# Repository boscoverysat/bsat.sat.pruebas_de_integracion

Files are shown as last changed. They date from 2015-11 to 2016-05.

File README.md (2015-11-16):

# Prebas de Integración

## Resumen

Este repositrio contiene tanto el código como la circuitería necesaria para poder realizar la implementación del satélite.

## Elementos

### [Processing](processing/)

Contiene el código empleado para poder llevar a cabo la representación gráfica del comportamiento del satélite.

### [PCB](pcb/)

Contiene los diseños y esquemas eléctricos correspondientes a las placas de circuito impreso empleadas para el satélite.

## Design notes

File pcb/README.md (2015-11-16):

# PCB

## Resumen

Esta sección del repositorio contiene los diseños y circuitos electrónicos correspondientes a las placas de circuito impreso del satélite.

## Elementos

### [Receptor RF 430MHz](receptor_rf_430mhz/)

Diseño de receptor para capturar localmente mediante Arduino, los datos enviados por el satélite.

### [SAT Battery Shield](sat_battery_shield/)

Diseño de la placa encargada de contener el sistema de alimentación del satélite.

### [SAT Control Shield](sat_control_shield/)

Diseño de la placa donde se ubicará el cerebro del del satélite así como los sitemas de control inercial y orientación.

### [SAT Transmission Shield](sat_transmission_shield/)

Diseño de la placa encargada de contener el sistema de transmisión por radiofrecuencia del satélite.

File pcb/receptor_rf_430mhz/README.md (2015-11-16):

# Receptor RF 430MHz

## Resumen

Esta sección del repositorio contiene el circuito electrónico y el diseño de placa de circuito impreso del receptor de radiofracuencia, para capturar localmente y mediante Arduino, los datos enviados desde el satélite.

El diseño electrónico se ha llevado a cabo mediante el software **Eagle PCB**.

#### Diseño PCB

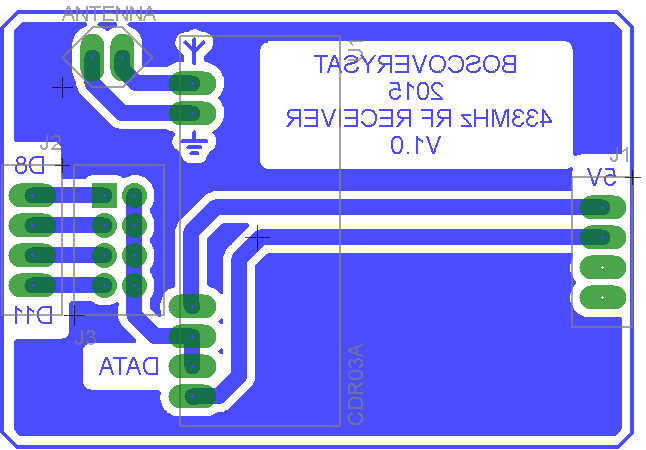
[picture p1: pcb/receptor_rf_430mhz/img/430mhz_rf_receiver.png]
Diseño de PCB


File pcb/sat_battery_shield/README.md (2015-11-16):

# SAT Battery Shield

## Resumen

Esta sección del repositorio contiene el circuito electrónico y el diseño de placa de circuito impreso para el sistema de alimentación del satélite.

El diseño electrónico se ha llevado a cabo mediante el software **Eagle PCB**.

#### Diseño PCB

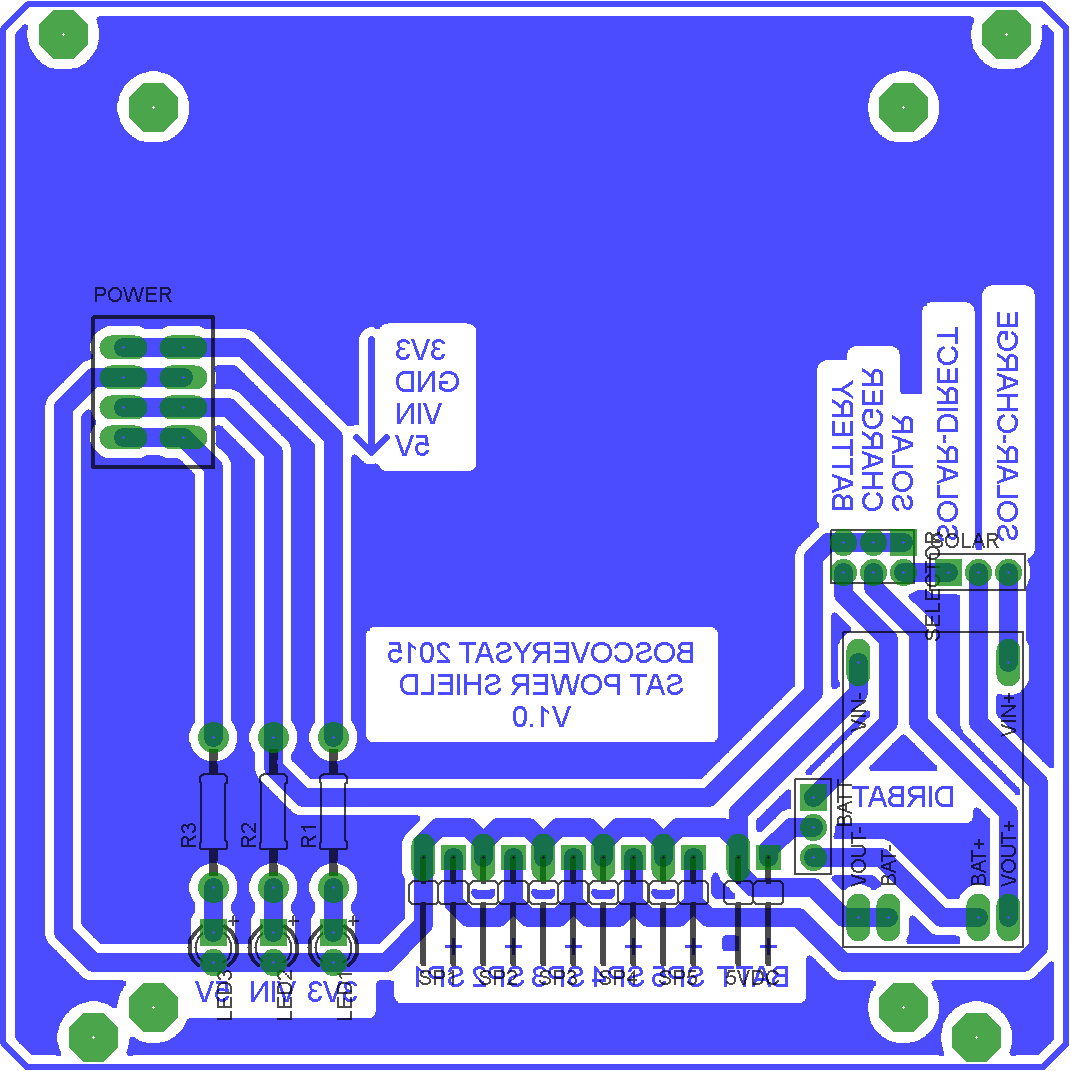
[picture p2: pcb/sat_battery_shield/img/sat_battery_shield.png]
Diseño de PCB


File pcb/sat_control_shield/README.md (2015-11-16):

# SAT Control Shield

## Resumen

Esta sección del repositorio contiene el circuito electrónico y el diseño de placa de circuito impreso para el sistema de control del satélite.

El diseño electrónico se ha llevado a cabo mediante el software **Eagle PCB**.

#### Diseño PCB

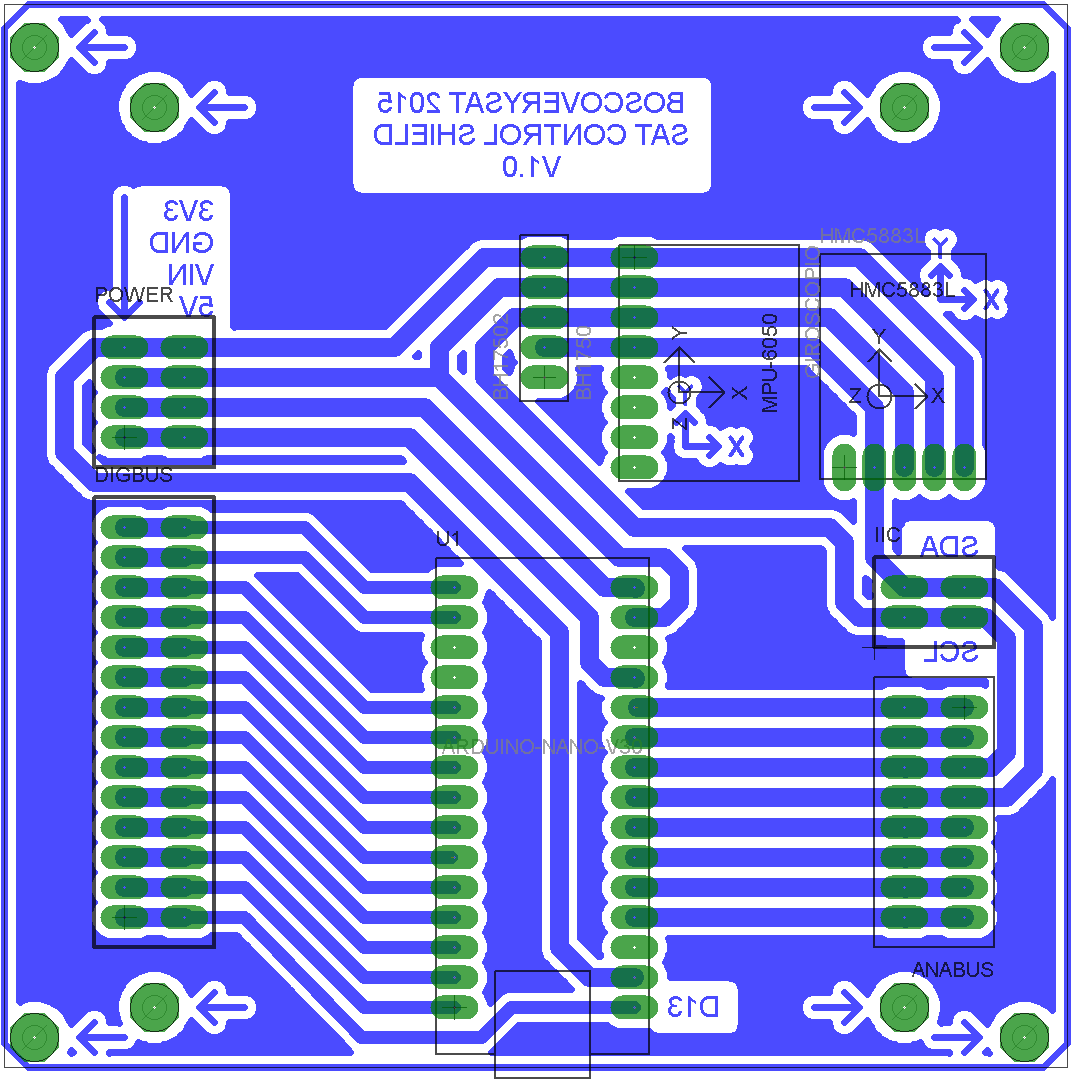
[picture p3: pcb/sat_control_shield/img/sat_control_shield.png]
Diseño de PCB


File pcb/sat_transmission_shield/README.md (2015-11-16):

# SAT Trasmission Shield

## Resumen

Esta sección del repositorio contiene el circuito electrónico y el diseño de placa de circuito impreso para el sistema de transmisión por radiofrecuencia del satélite.

El diseño electrónico se ha llevado a cabo mediante el software **Eagle PCB**.

#### Diseño PCB

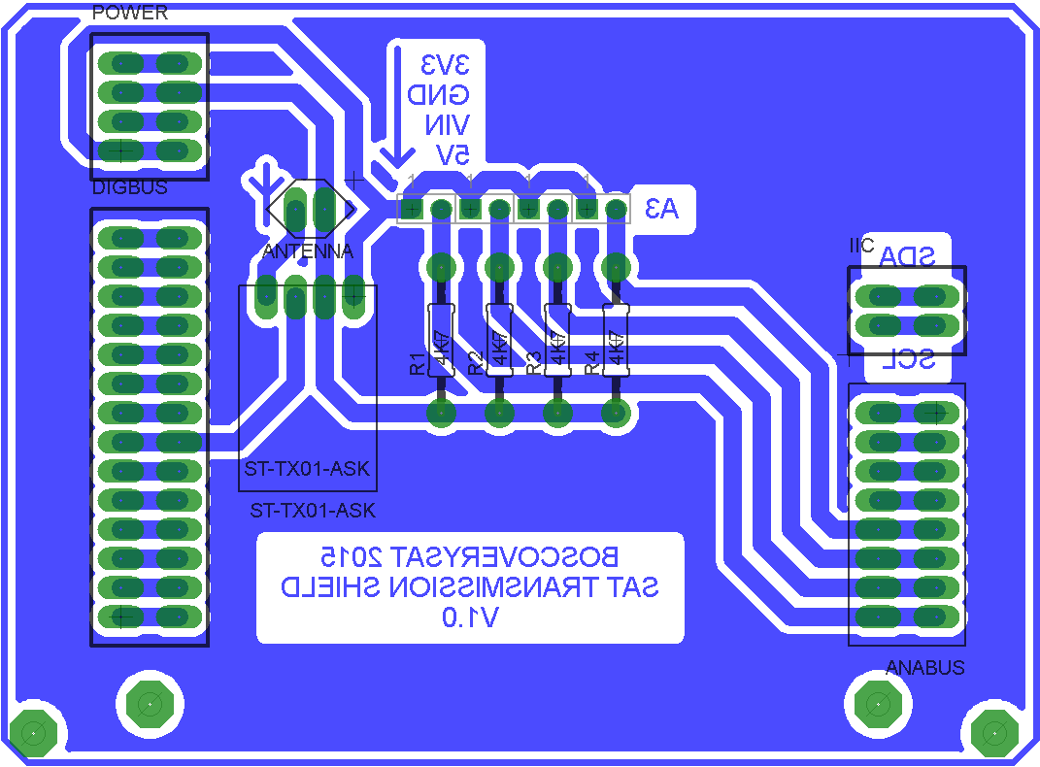
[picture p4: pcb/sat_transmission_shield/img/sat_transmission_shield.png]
Diseño de PCB


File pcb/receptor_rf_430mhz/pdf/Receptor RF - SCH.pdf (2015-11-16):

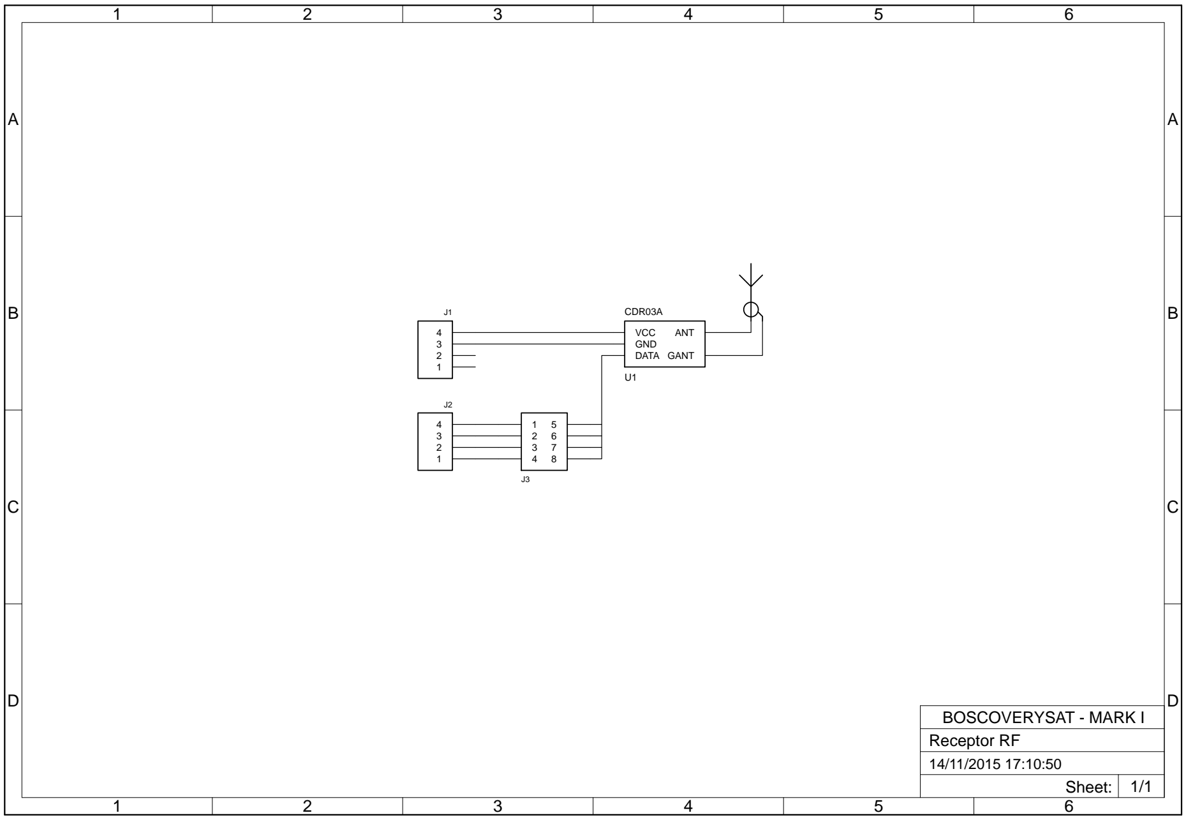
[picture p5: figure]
CDR03A; VCC; DATA; GND; ANT; GANT; Receptor RF; Sheet: 1/1; BOSCOVERYSAT - MARK I

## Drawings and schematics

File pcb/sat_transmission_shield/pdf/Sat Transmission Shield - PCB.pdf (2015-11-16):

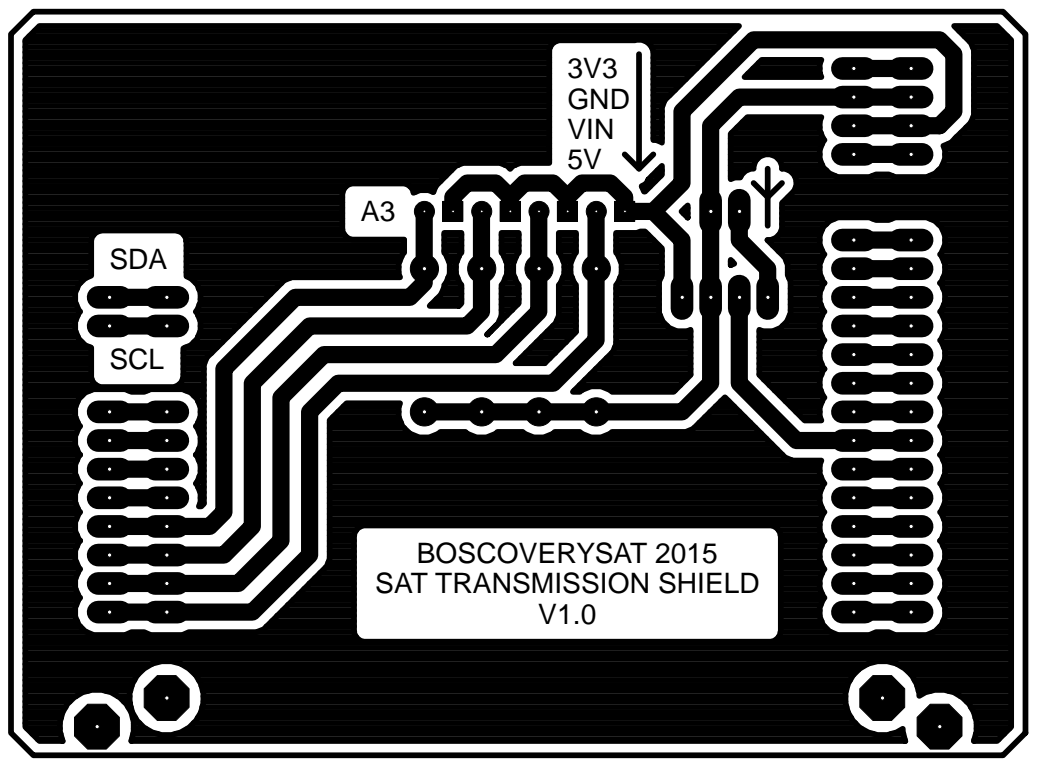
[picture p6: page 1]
3V3 GND VIN 5V; SCL; SDA

BOSCOVERYSAT 2015
SAT TRANSMISSION SHIELD

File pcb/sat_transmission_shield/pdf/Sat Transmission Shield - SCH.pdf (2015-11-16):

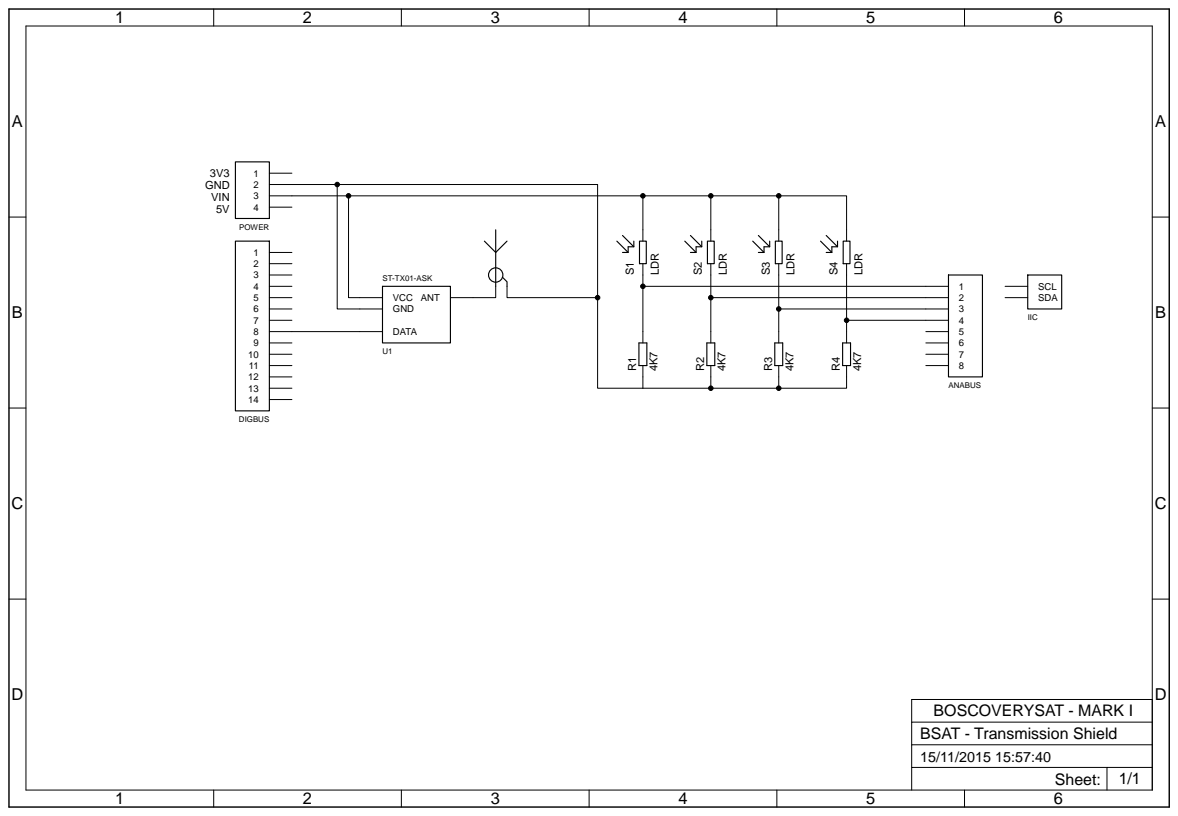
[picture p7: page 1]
3V3 GND VIN 5V; ST-TX01-ASK; LDR 4K7; DIGBUS; POWER; SCL SDA; IIC; VCC GND; DATA; ANT; ANABUS; Sheet: 1/1

BOSCOVERYSAT - MARK I
BSAT - Transmission Shield

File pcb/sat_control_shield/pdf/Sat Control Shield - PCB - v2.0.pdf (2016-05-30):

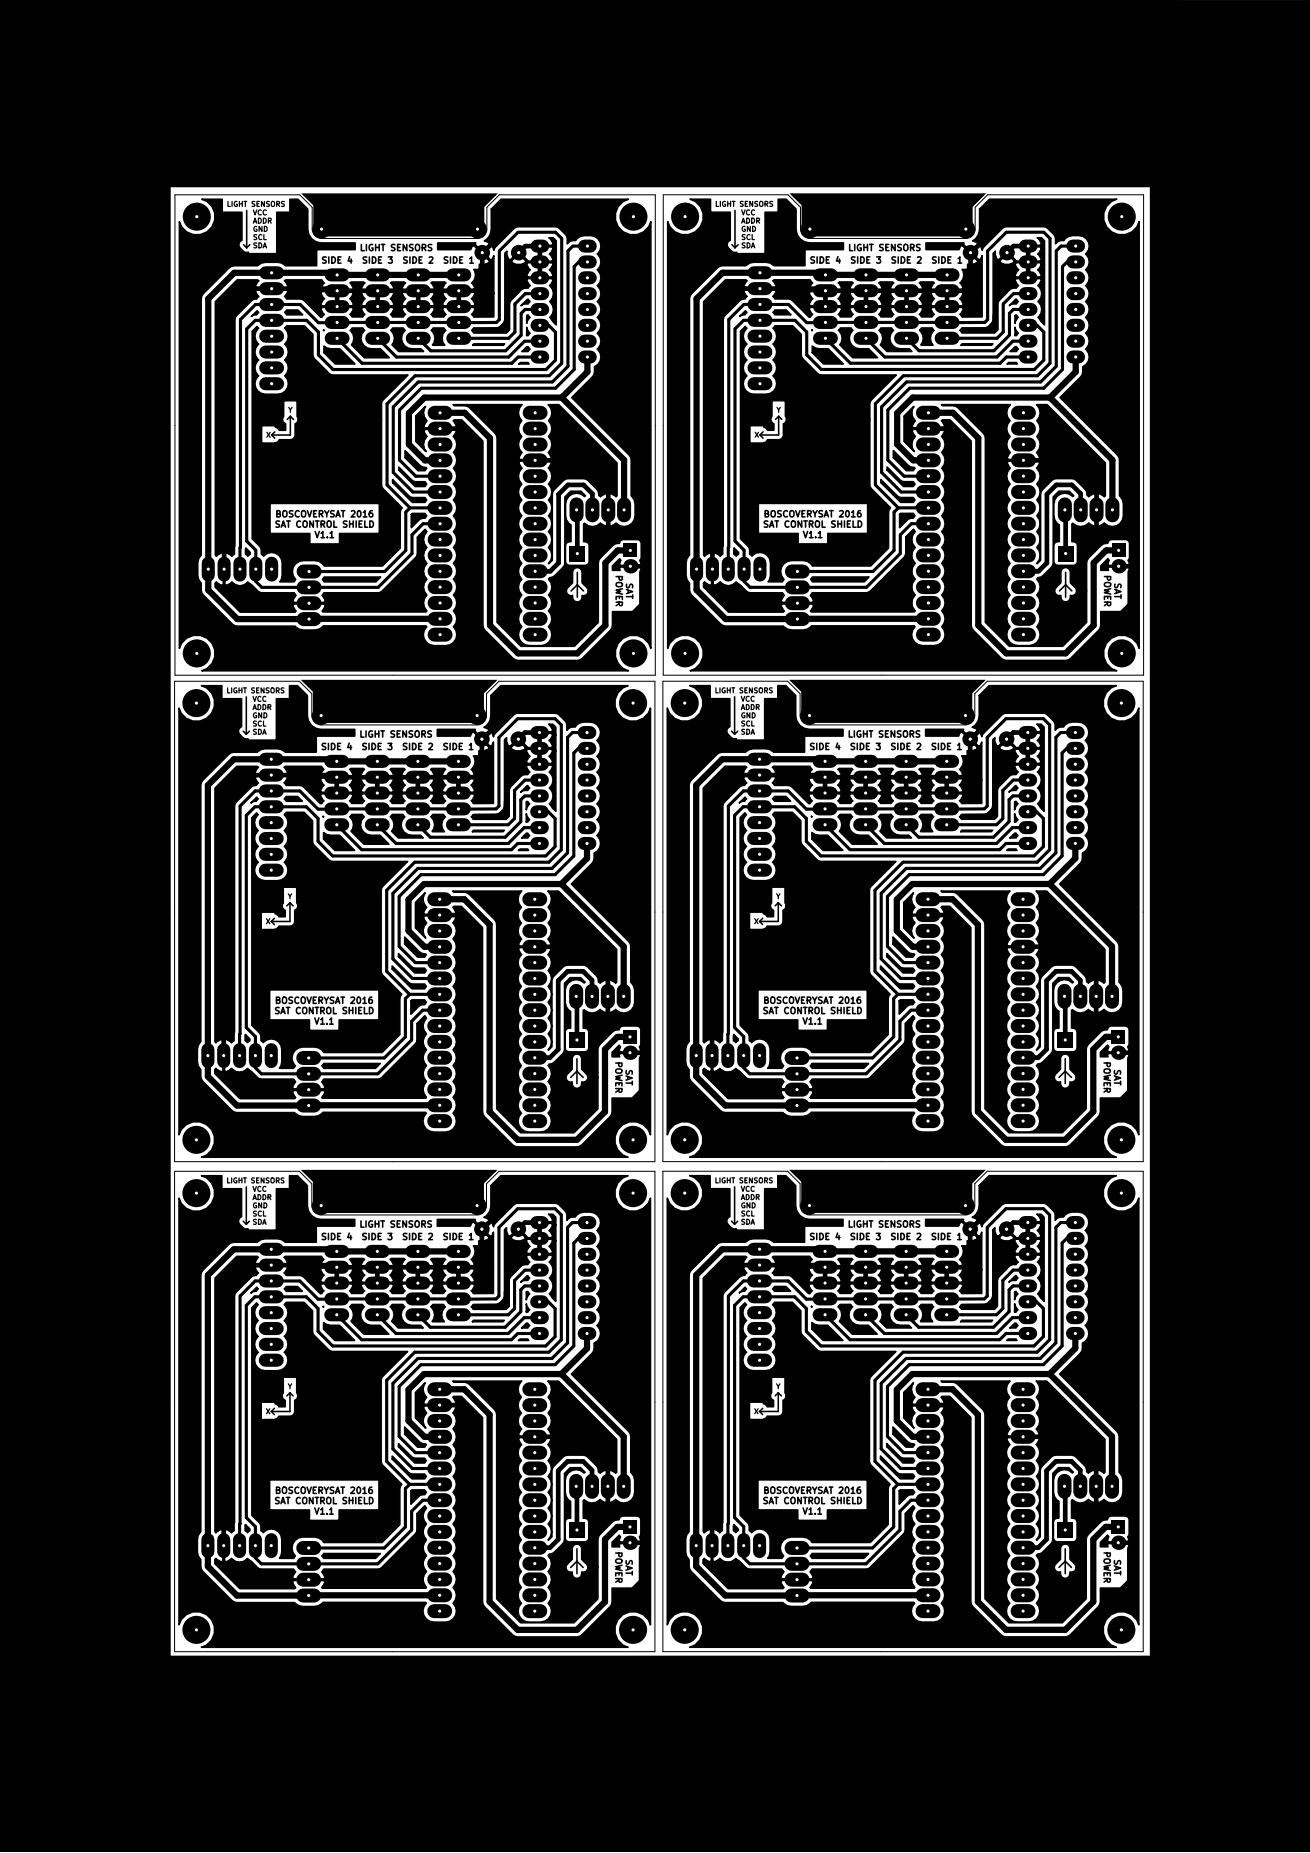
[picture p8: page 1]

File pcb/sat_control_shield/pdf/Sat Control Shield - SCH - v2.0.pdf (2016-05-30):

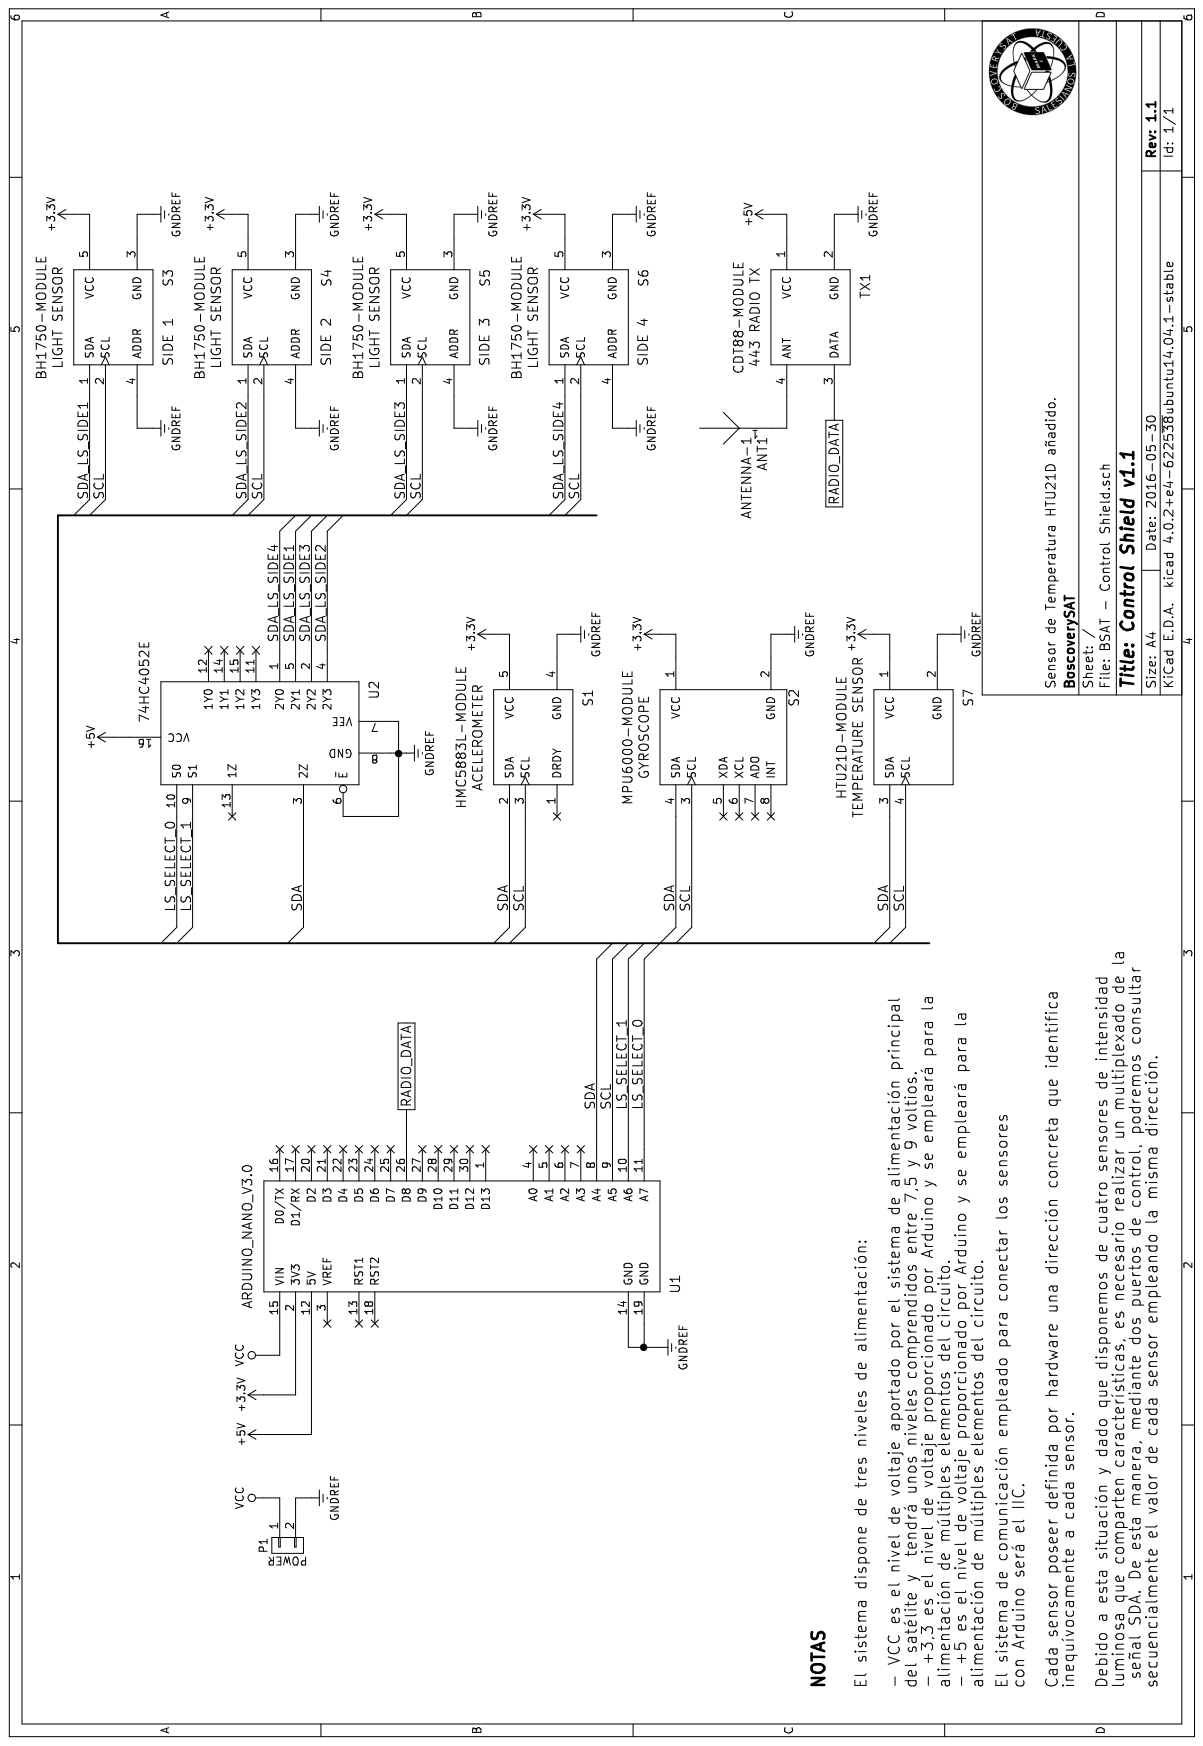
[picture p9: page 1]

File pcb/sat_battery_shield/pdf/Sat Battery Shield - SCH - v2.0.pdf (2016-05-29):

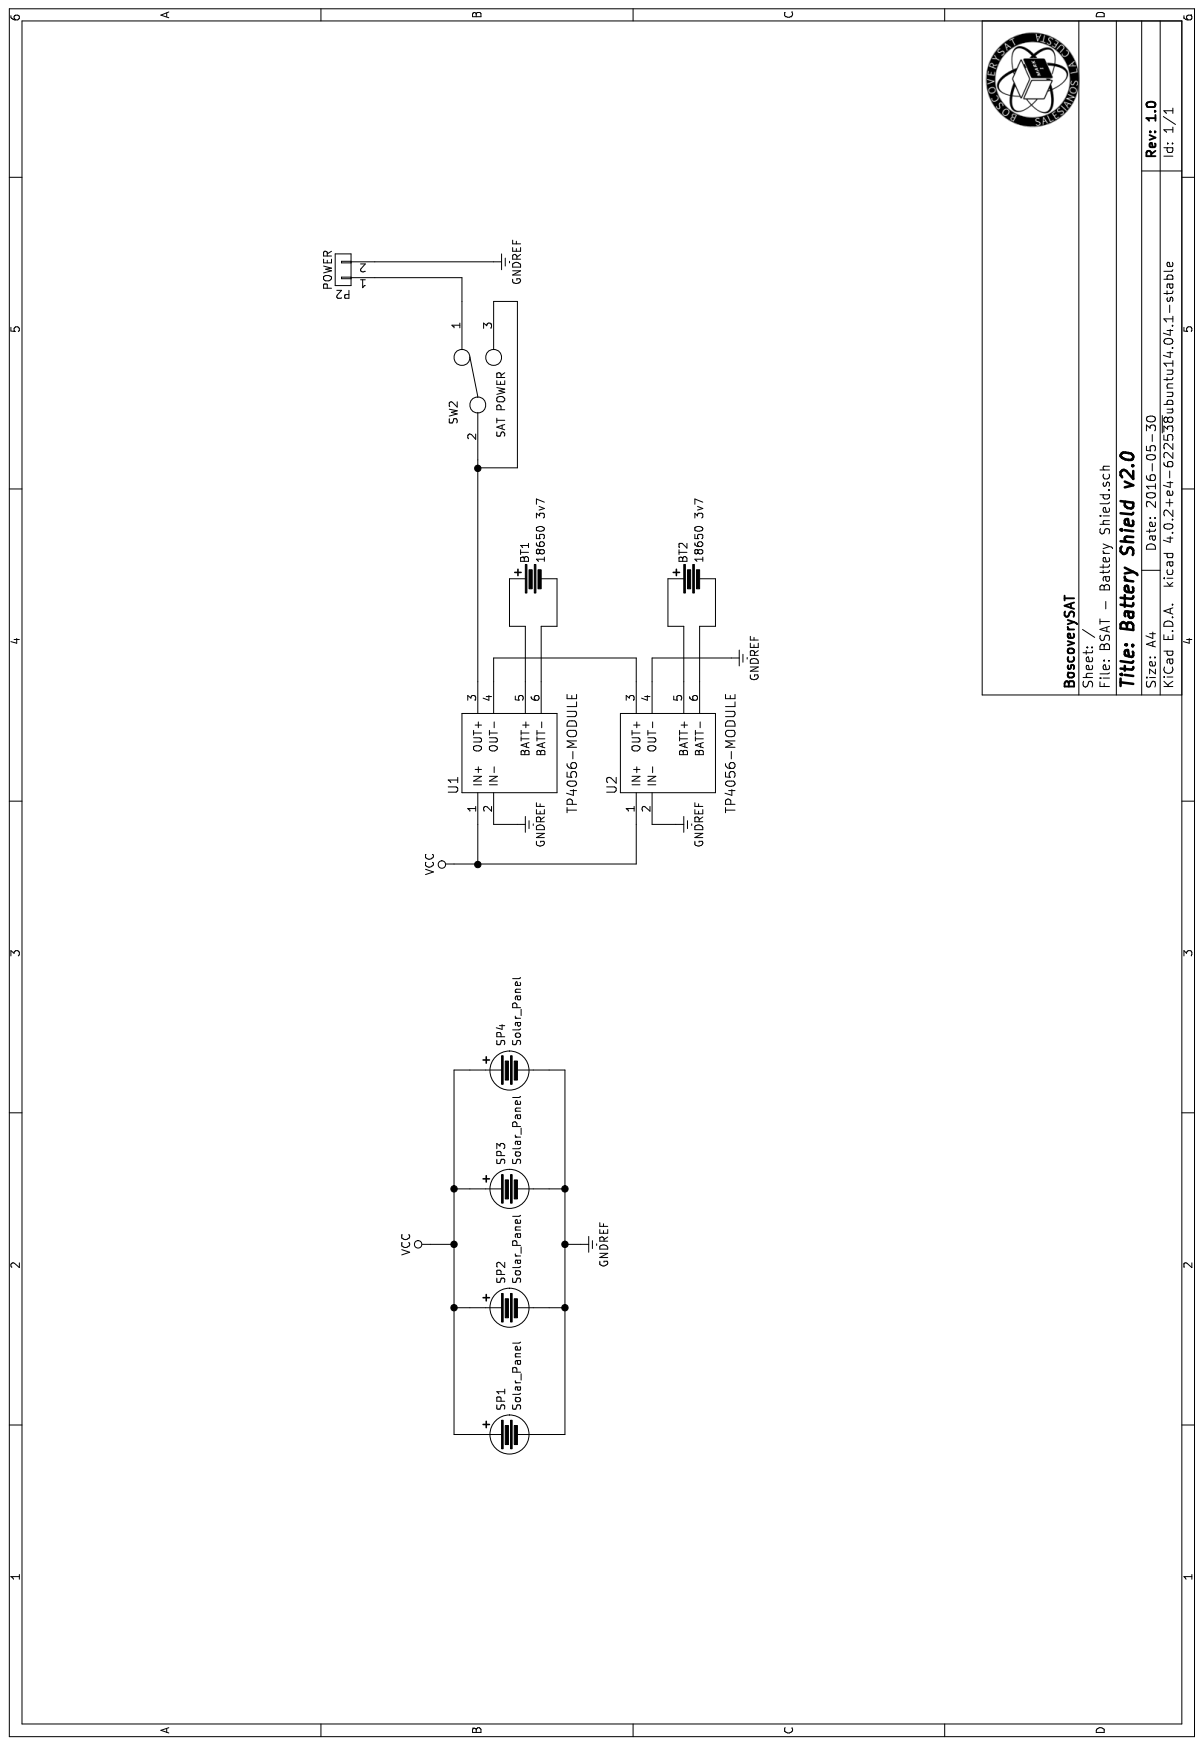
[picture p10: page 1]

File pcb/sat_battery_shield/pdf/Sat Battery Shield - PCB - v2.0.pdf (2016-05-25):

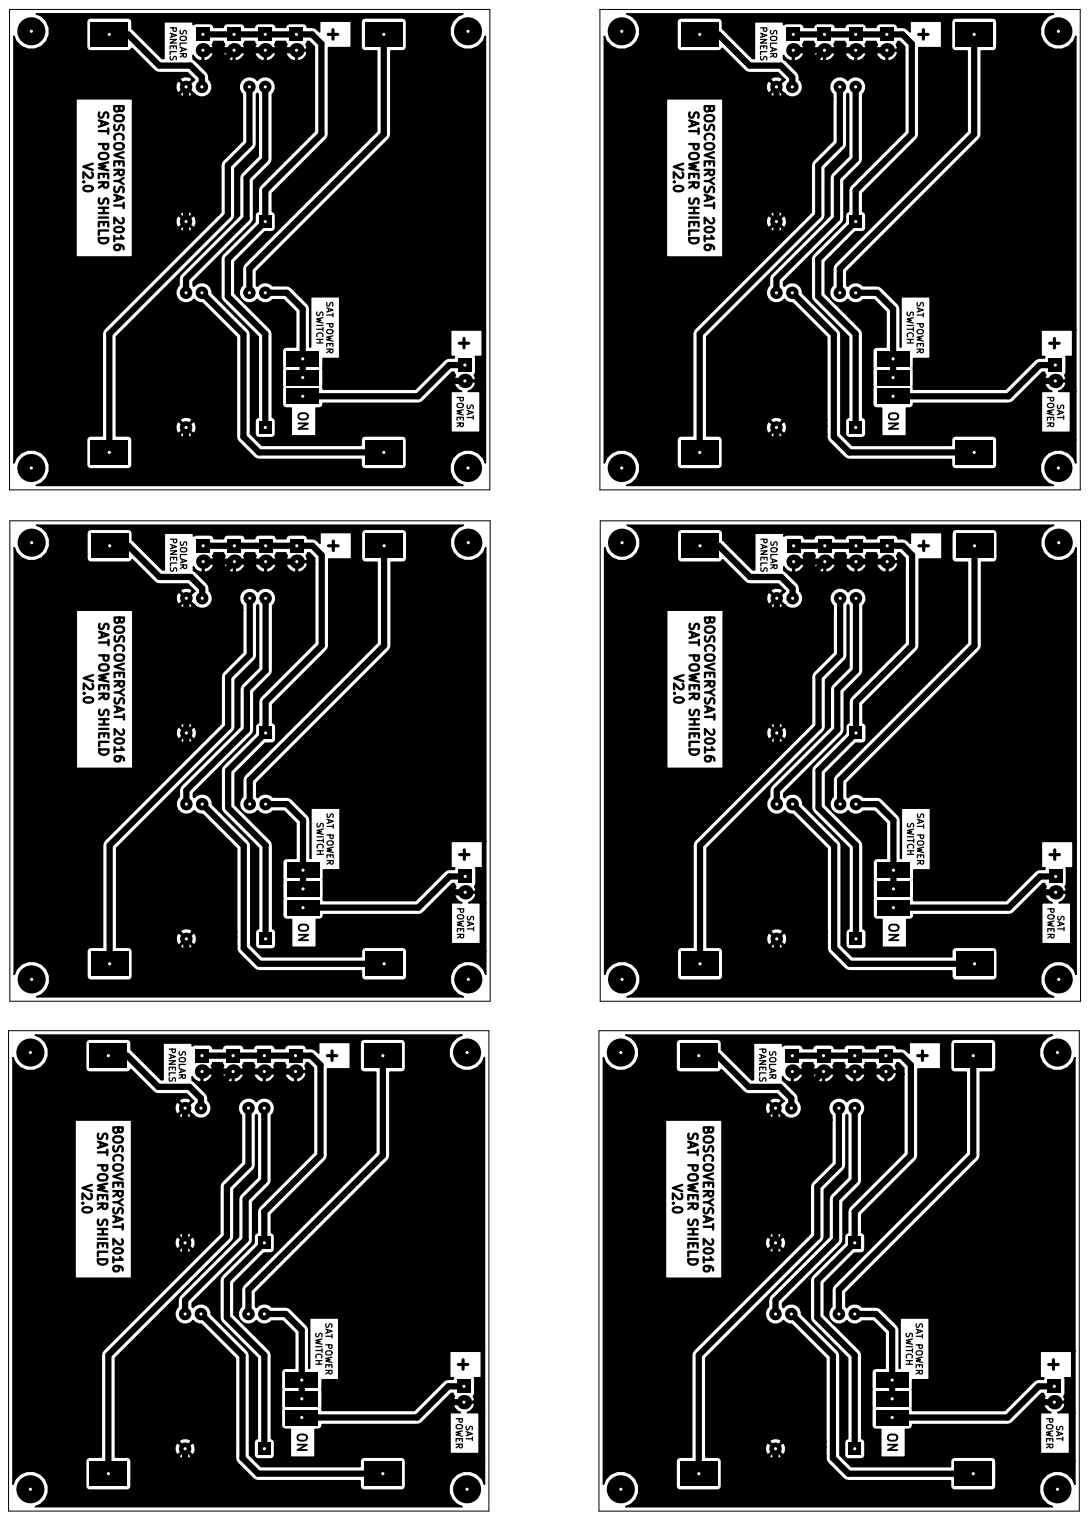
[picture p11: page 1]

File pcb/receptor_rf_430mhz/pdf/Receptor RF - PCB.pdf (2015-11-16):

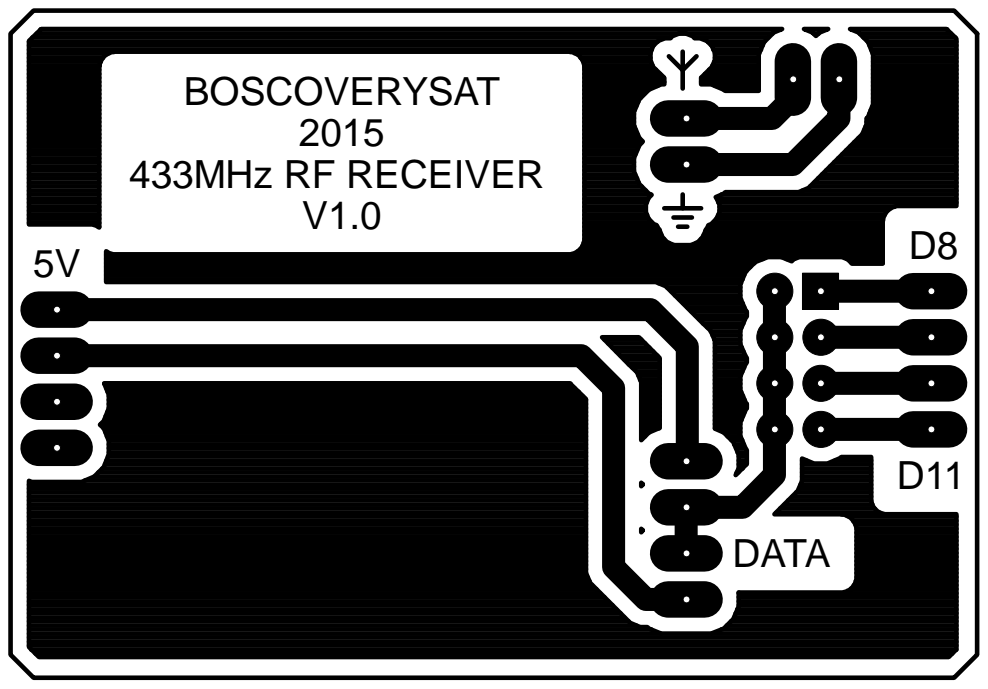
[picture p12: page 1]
BOSCOVERYSAT 2015 433MHz RF RECEIVER V1.0; DATA

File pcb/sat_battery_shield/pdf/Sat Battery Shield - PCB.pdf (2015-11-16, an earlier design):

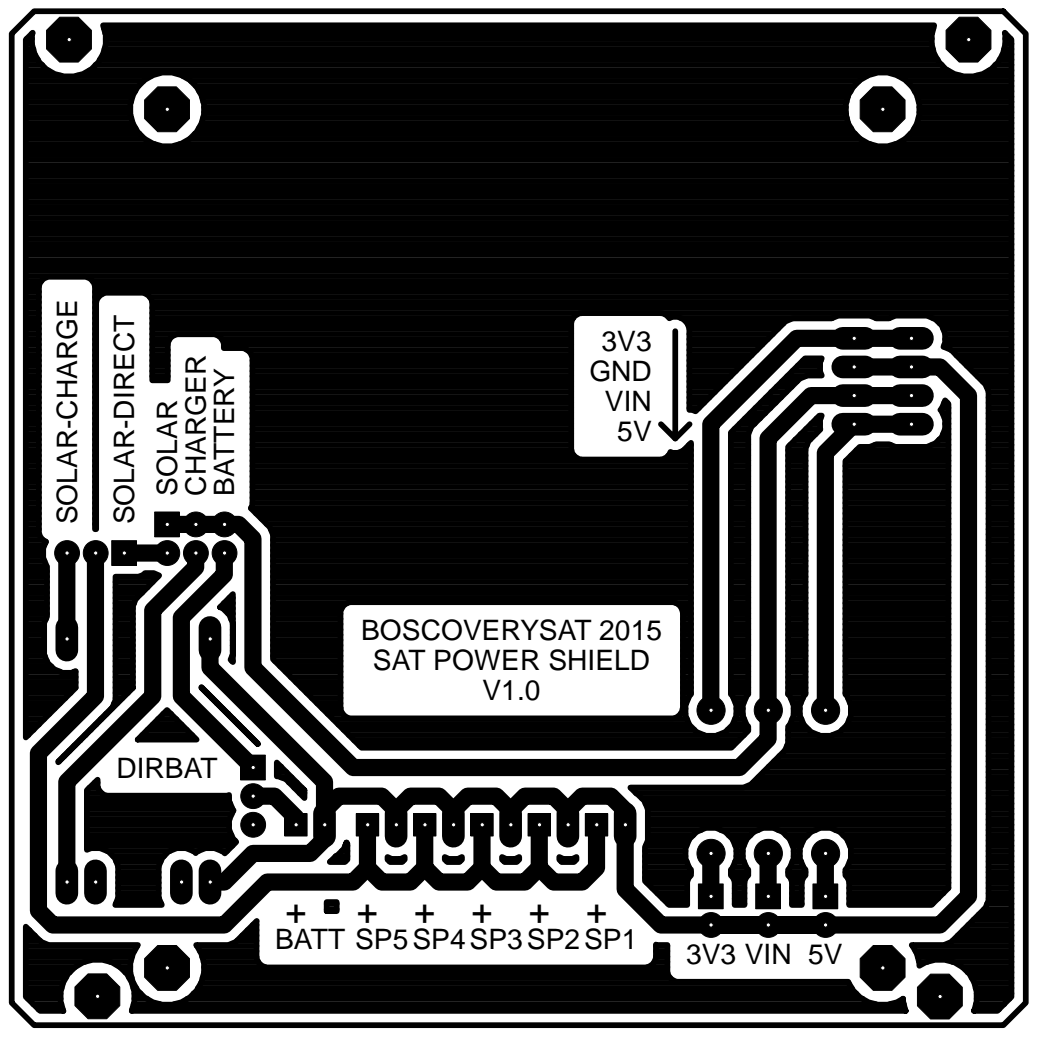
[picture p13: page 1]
BATT SP5SP4SP3SP2SP1; 3V3 VIN 5V; DIRBAT; SOLAR-CHARGE; SOLAR-DIRECT; SOLAR; CHARGER BATTERY; 3V3 GND VIN 5V

BOSCOVERYSAT 2015
SAT POWER SHIELD

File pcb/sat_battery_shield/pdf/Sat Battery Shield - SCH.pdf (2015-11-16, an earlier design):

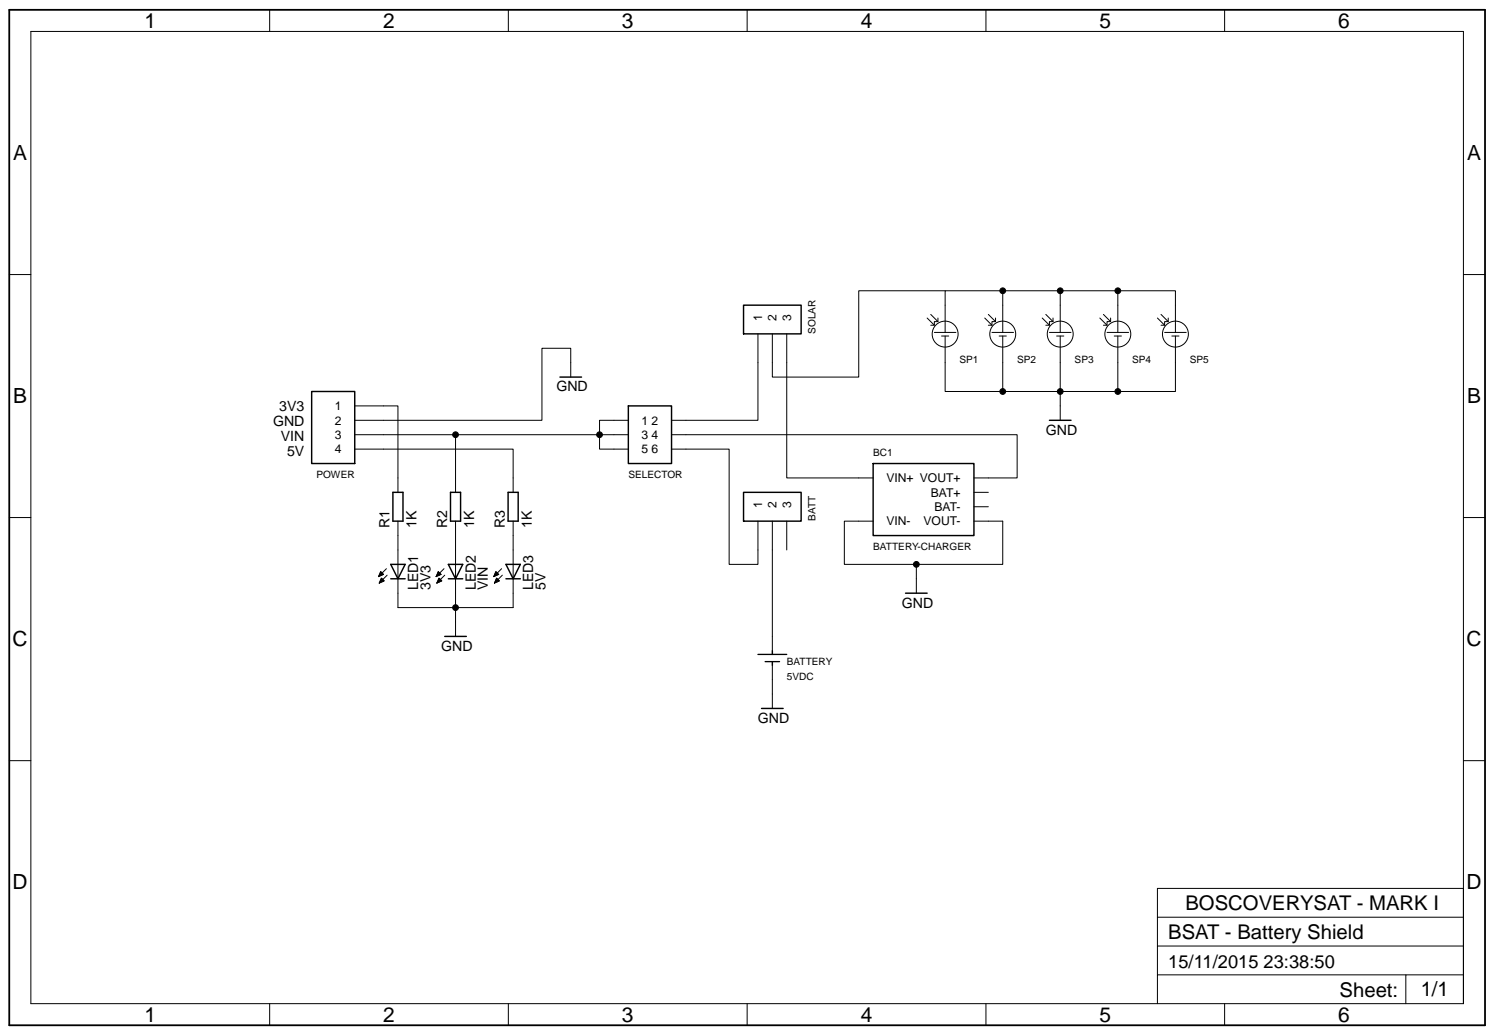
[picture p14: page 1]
3V3 GND VIN 5V; BATTERY-CHARGER; BATTERY; GND; VIN; POWER; SELECTOR; VIN+ VOUT+; BAT+ BAT- VIN- VOUT-; BATT; 5VDC; LED1; LED2; LED3; SOLAR; Sheet: 1/1

BOSCOVERYSAT - MARK I
BSAT - Battery Shield

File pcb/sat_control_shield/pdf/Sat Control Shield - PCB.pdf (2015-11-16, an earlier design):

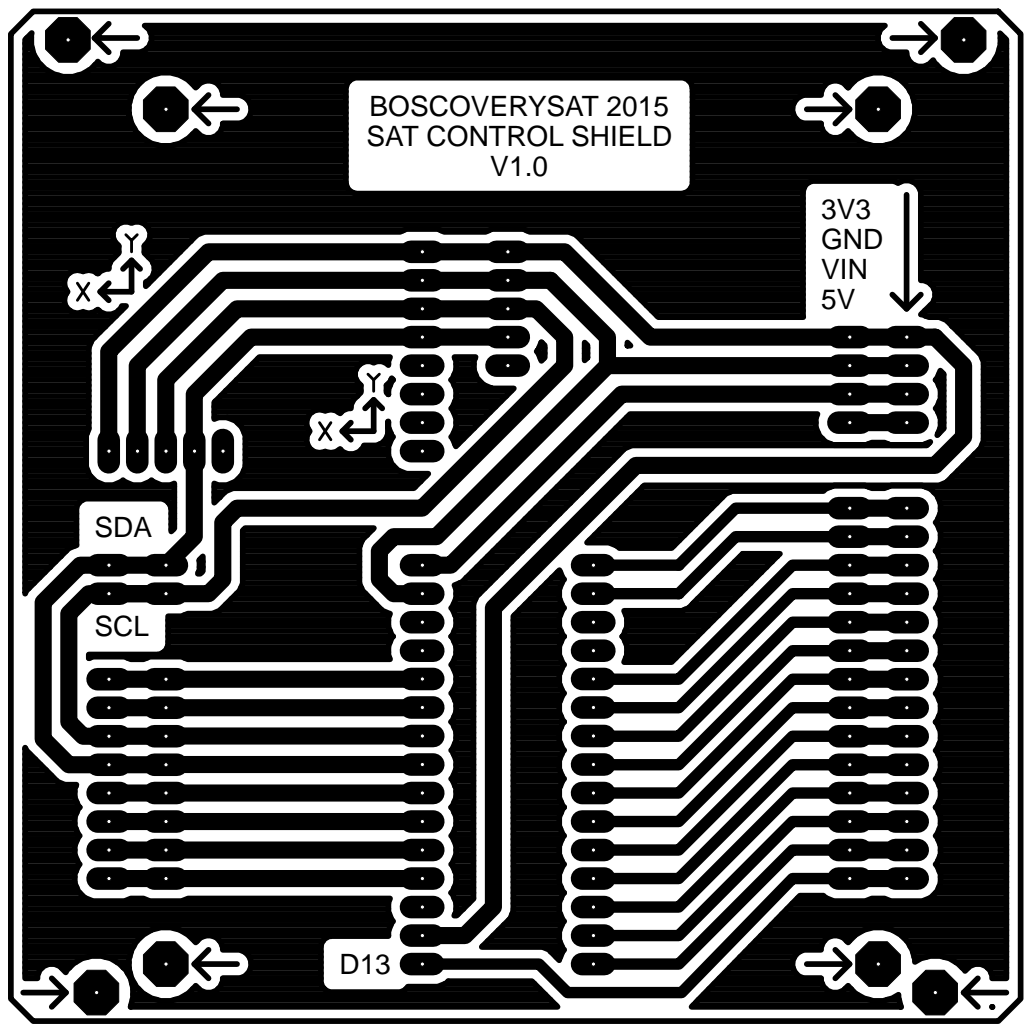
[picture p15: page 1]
SDA; SCL; 3V3 GND VIN 5V

BOSCOVERYSAT 2015
SAT CONTROL SHIELD

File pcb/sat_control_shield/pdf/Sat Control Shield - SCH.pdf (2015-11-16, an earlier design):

A

A

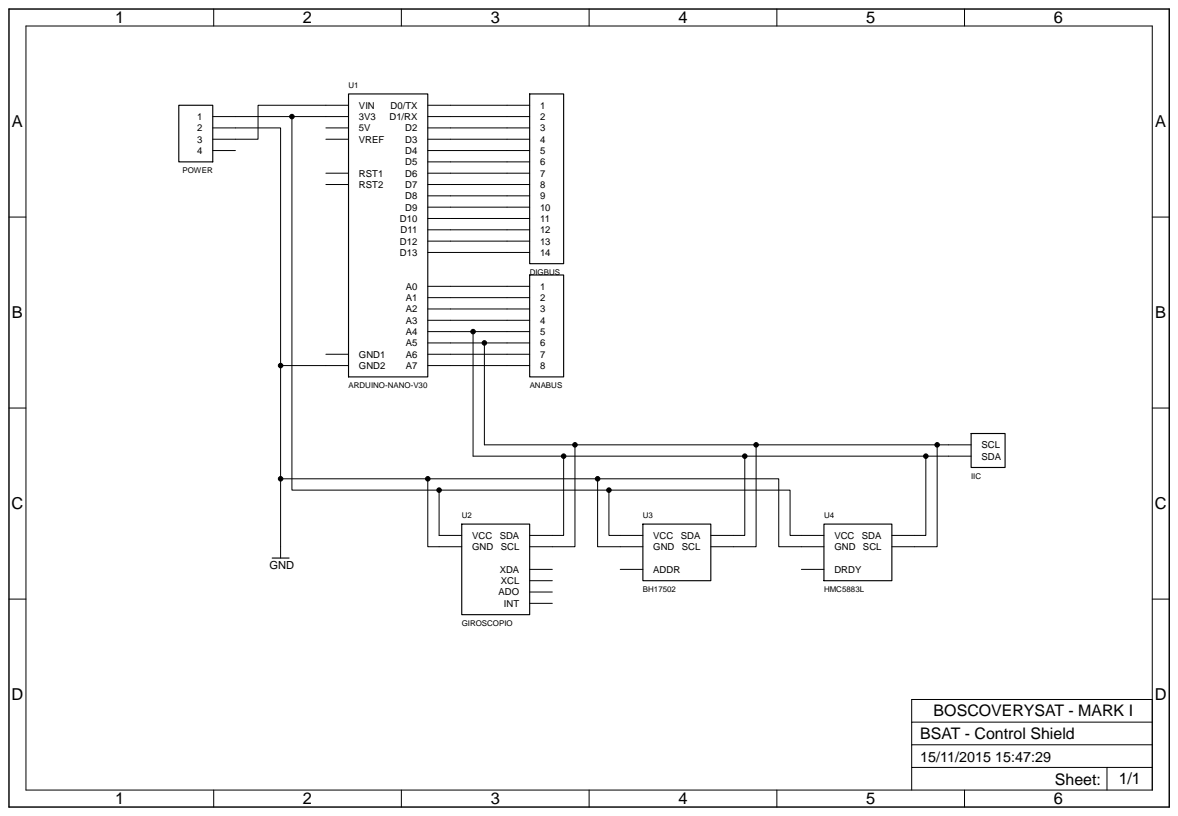
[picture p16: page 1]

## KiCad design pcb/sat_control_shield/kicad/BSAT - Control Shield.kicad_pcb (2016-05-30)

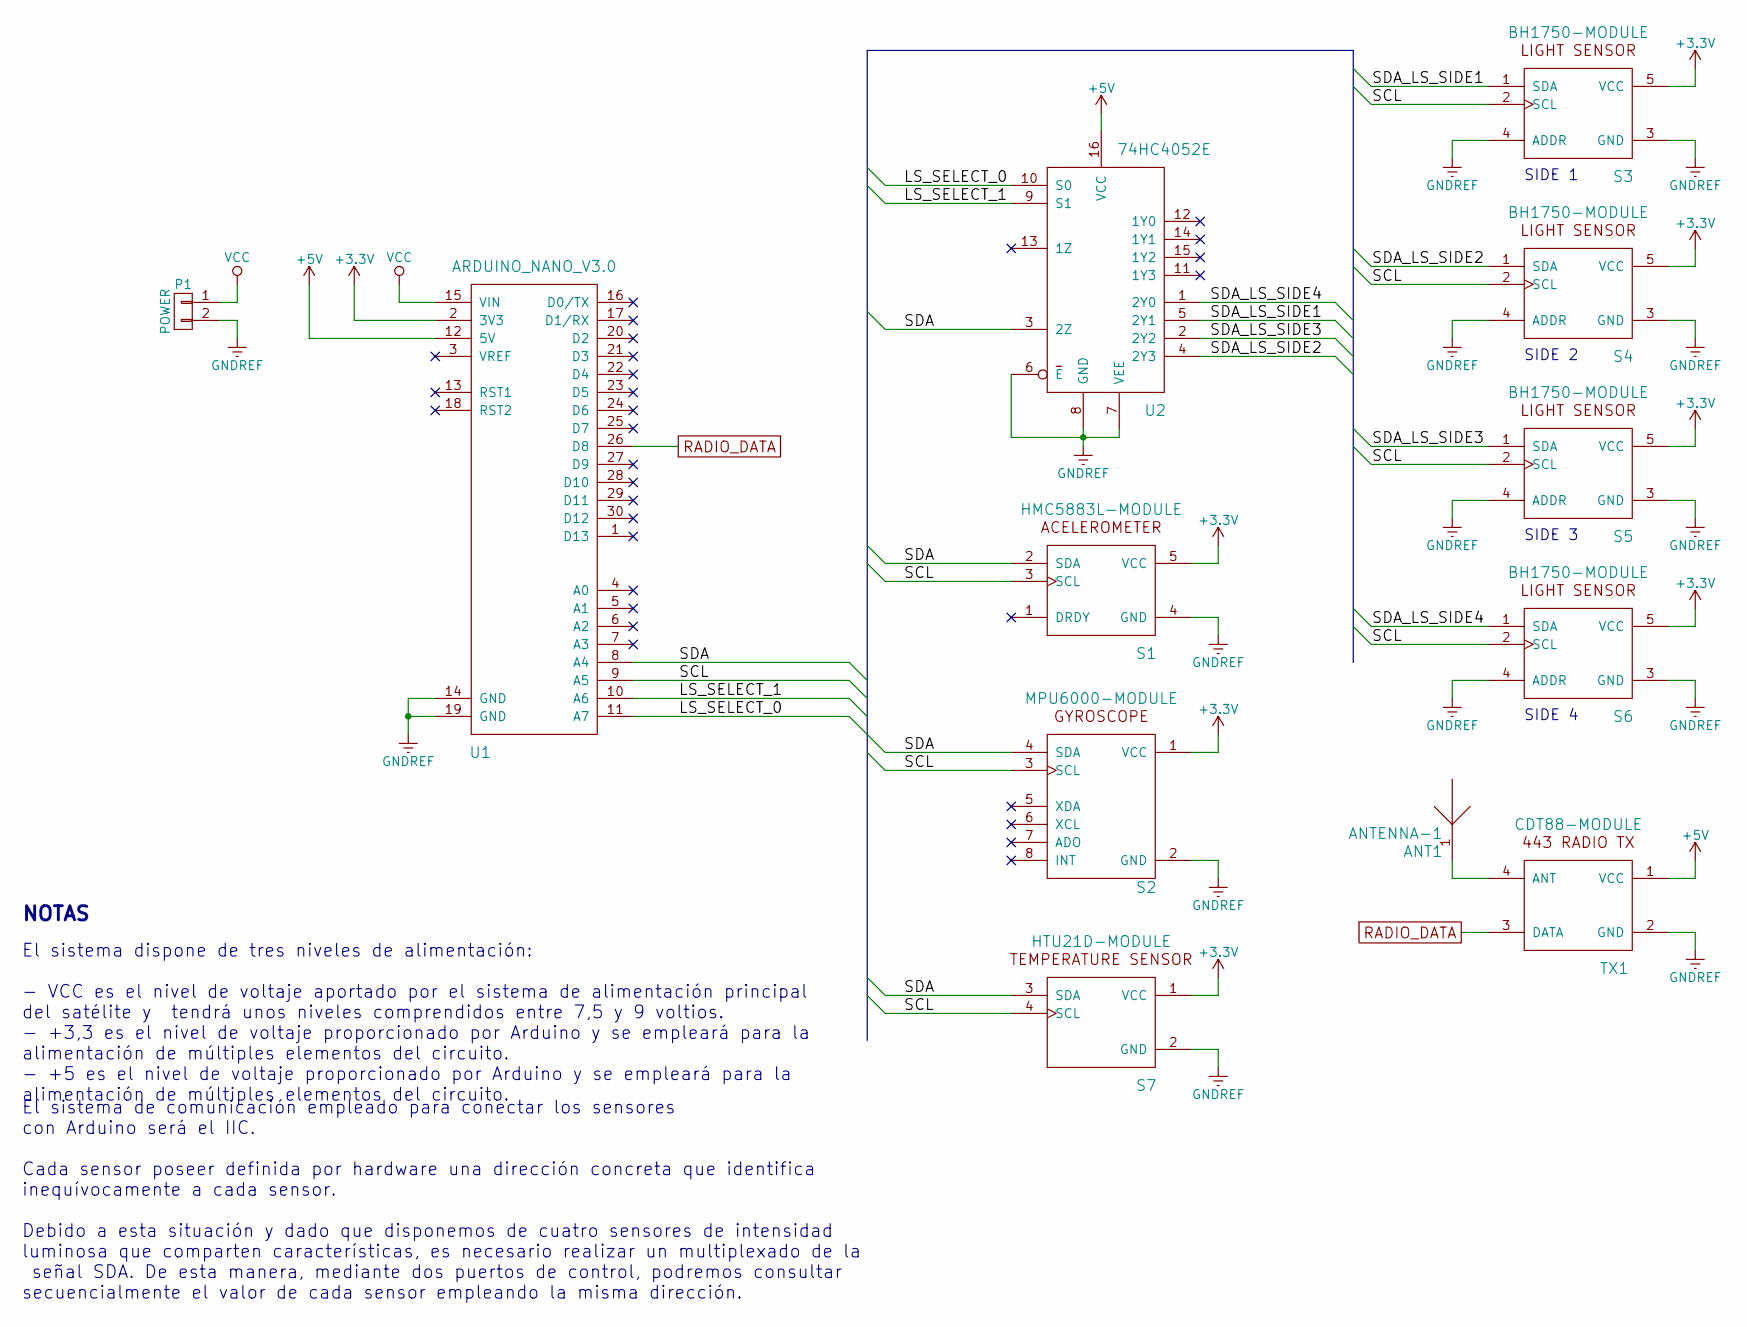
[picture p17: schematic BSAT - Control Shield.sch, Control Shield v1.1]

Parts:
ANT1: ANTENNA-1; Pin_Header_Angled_1x01
P1: POWER; Pin_Header_Straight_1x02
S1: HMC5883L-MODULE; HMC5883L
S2: MPU6000-MODULE; MPU-6000
S3, S4, S5, S6: BH1750-MODULE
S7: HTU21D-MODULE
TX1: CDT88-MODULE; CDT-88
U1: ARDUINO_NANO_V3.0
U2: 74HC4052E; DIP-16_W7.62mm_LongPads

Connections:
+3V3: S1.5 (VCC), S2.1 (VCC), S3.5 (VCC), S4.5 (VCC), S5.5 (VCC), S6.5 (VCC), S7.1 (VCC), U1.2 (3V3)
+5V: TX1.1 (VCC), U1.12 (5V), U2.16 (VCC)
/LS_SELECT_0: U1.11 (A7), U2.10 (S0)
/LS_SELECT_1: U1.10 (A6), U2.9 (S1)
/SCL: S1.3 (SCL), S2.3 (SCL), S3.2 (SCL), S4.2 (SCL), S5.2 (SCL), S6.2 (SCL), S7.4 (SCL), U1.9 (A5)
/SDA: S1.2 (SDA), S2.4 (SDA), S7.3 (SDA), U1.8 (A4), U2.3 (2Z)
/SDA_LS_SIDE1: S3.1 (SDA), U2.5 (2Y1)
/SDA_LS_SIDE2: S4.1 (SDA), U2.4 (2Y3)
/SDA_LS_SIDE3: S5.1 (SDA), U2.2 (2Y2)
/SDA_LS_SIDE4: S6.1 (SDA), U2.1 (2Y0)
GNDREF: P1.2, S1.4 (GND), S2.2 (GND), S3.3 (GND), S3.4 (ADDR), S4.3 (GND), S4.4 (ADDR), S5.3 (GND), S5.4 (ADDR), S6.3 (GND), S6.4 (ADDR), S7.2 (GND), TX1.2 (GND), U1.14 (GND), U1.19 (GND), U2.6 (E), U2.7 (VEE), U2.8 (GND)
unnamed: ANT1.1, TX1.4 (ANT)
RADIO_DATA: TX1.3 (DATA), U1.26 (D8)
VCC: P1.1, U1.15 (VIN)

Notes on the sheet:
SIDE 1
SIDE 2
SIDE 3
SIDE 4
NOTAS
El sistema dispone de tres niveles de alimentación: - VCC es el nivel de voltaje aportado por el sistema de alimentación principal del satélite y tendrá unos niveles comprendidos entre 7,5 y 9 voltios. - +3,3 es el nivel de voltaje proporcionado por Arduino y se empleará para la alimentación de múl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
El sistema de comunicación empleado para conectar los sensores con Arduino será el IIC. Cada sensor poseer definida por hardware una dirección concreta que identifica inequívocamente a cada sensor. Debido a esta situación y dado que disponemos de cuatro sensores de intensidad luminosa que comparten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

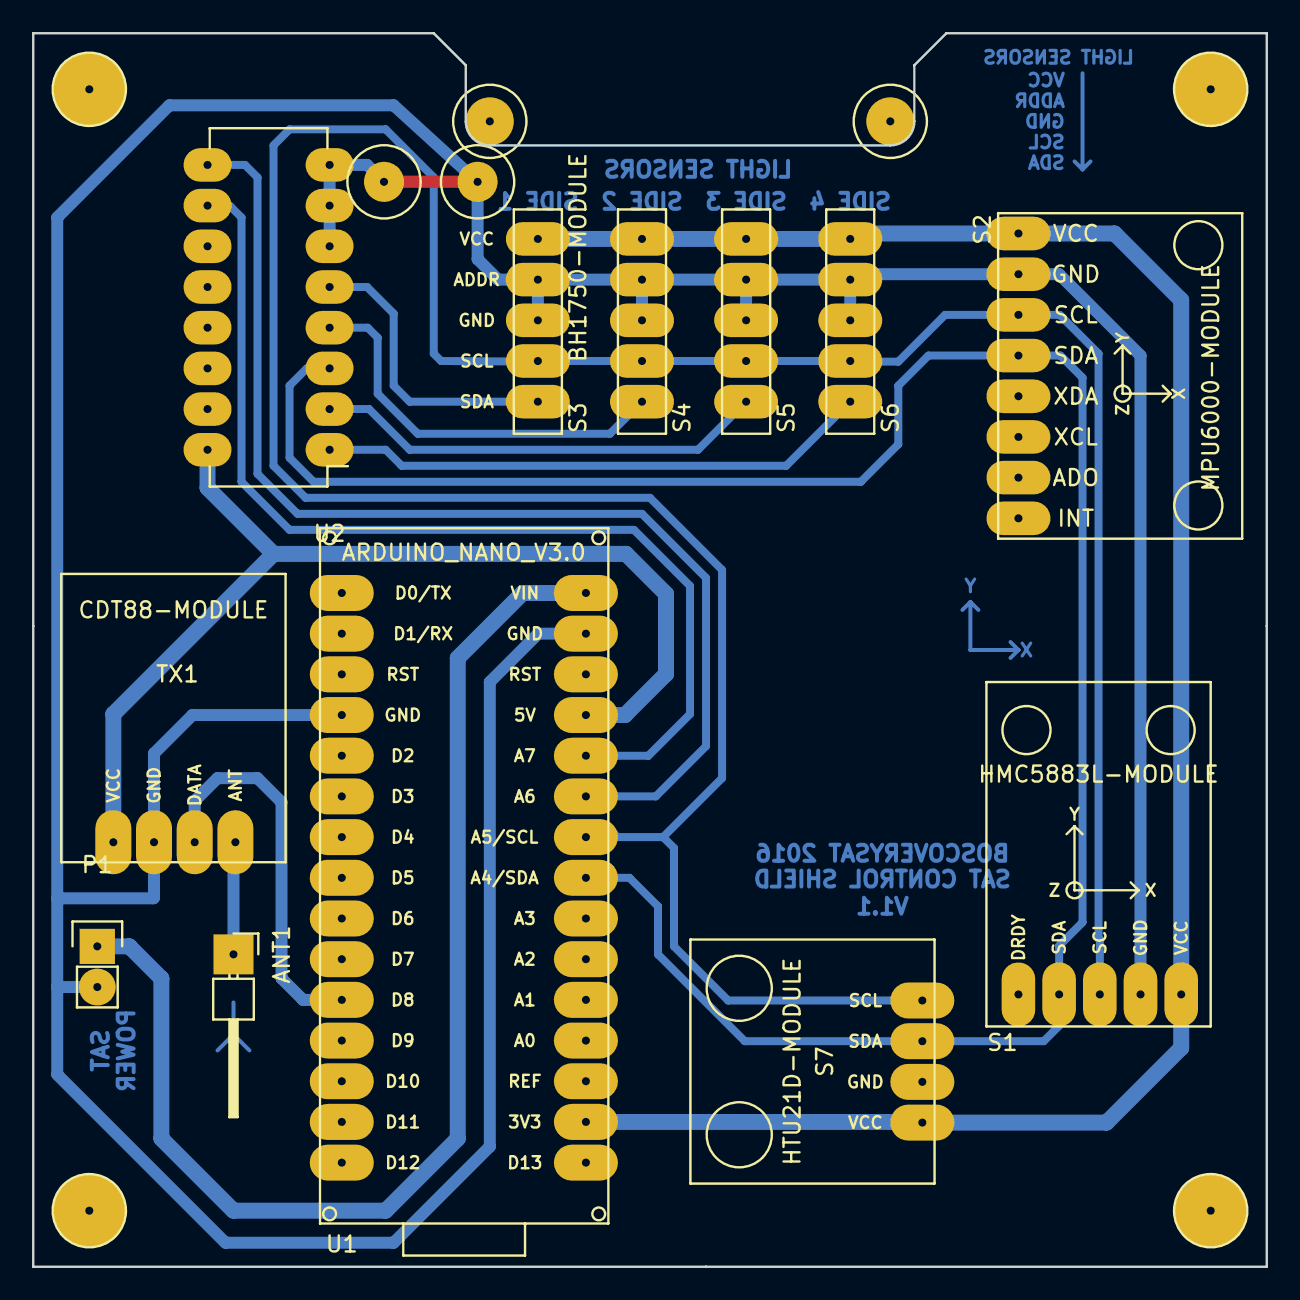
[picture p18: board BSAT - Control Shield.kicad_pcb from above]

Board: 2 copper layers, 77.0 x 77.0 mm, 12 parts (0 on the bottom side), 14 nets.

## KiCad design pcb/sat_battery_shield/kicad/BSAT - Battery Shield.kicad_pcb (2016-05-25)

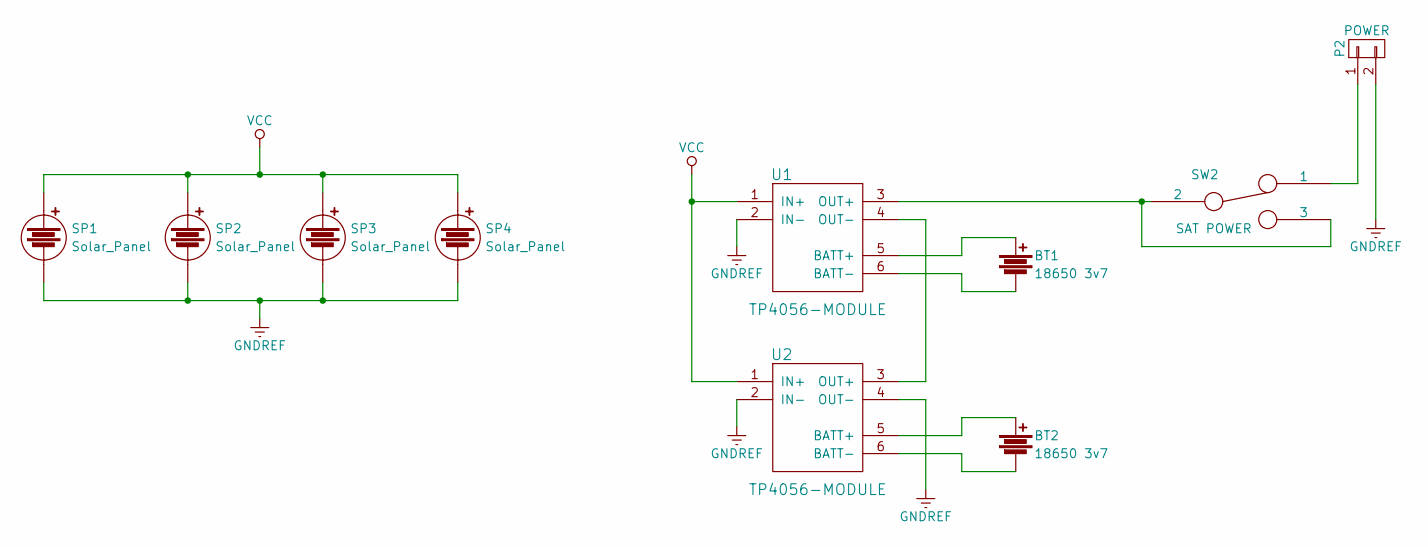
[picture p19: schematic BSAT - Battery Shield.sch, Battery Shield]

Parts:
BT1, BT2: 18650 3v7; BATT-18650
P2: POWER; Pin_Header_Straight_1x02
SP1, SP2, SP3, SP4: Solar_Panel; Pin_Header_Straight_1x02
SW2: SAT POWER; SWITCH-1CIR-2CON
U1, U2: TP4056-MODULE

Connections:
GNDREF: P2.2, SP1.2, SP2.2, SP3.2, SP4.2, U1.2 (IN-), U2.2 (IN-), U2.4 (OUT-)
unnamed: BT1.1, U1.5 (BATT+)
unnamed: BT1.2, U1.6 (BATT-)
unnamed: BT2.1, U2.5 (BATT+)
unnamed: BT2.2, U2.6 (BATT-)
unnamed: P2.1, SW2.1
unnamed: SW2.2, SW2.3, U1.3 (OUT+)
unnamed: U1.4 (OUT-), U2.3 (OUT+)
VCC: SP1.1, SP2.1, SP3.1, SP4.1, U1.1 (IN+), U2.1 (IN+)

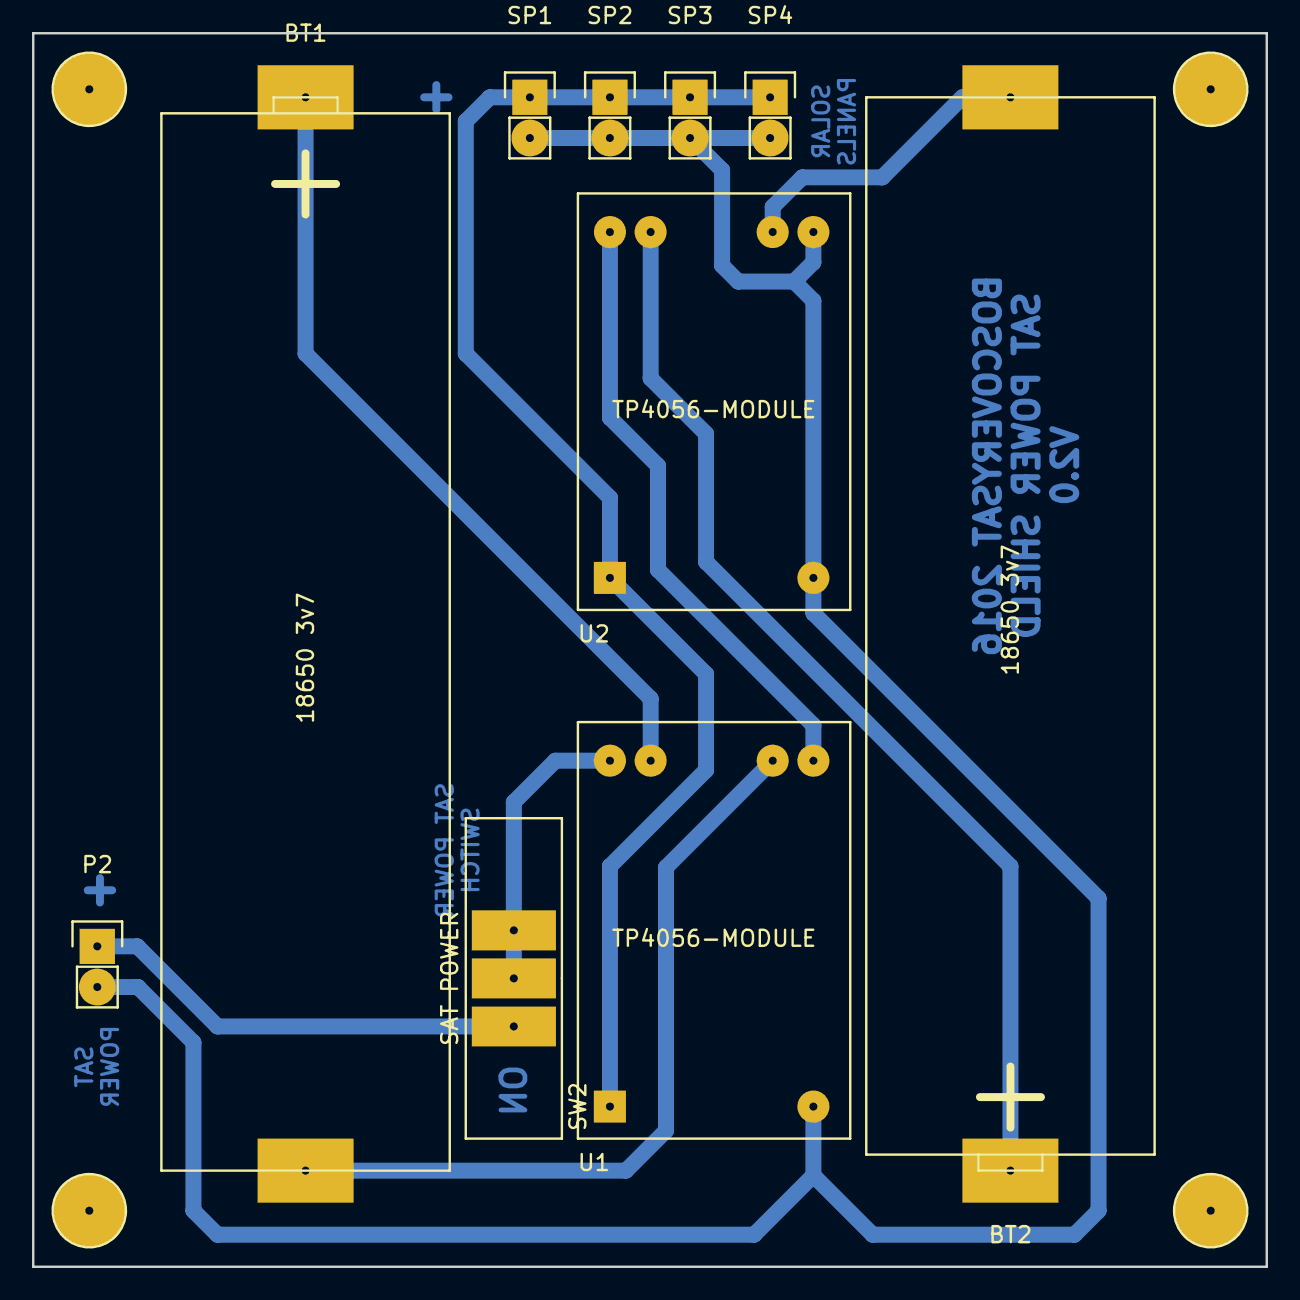
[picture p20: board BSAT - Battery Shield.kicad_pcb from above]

Board: 2 copper layers, 77.0 x 77.0 mm, 10 parts (0 on the bottom side), 9 nets.

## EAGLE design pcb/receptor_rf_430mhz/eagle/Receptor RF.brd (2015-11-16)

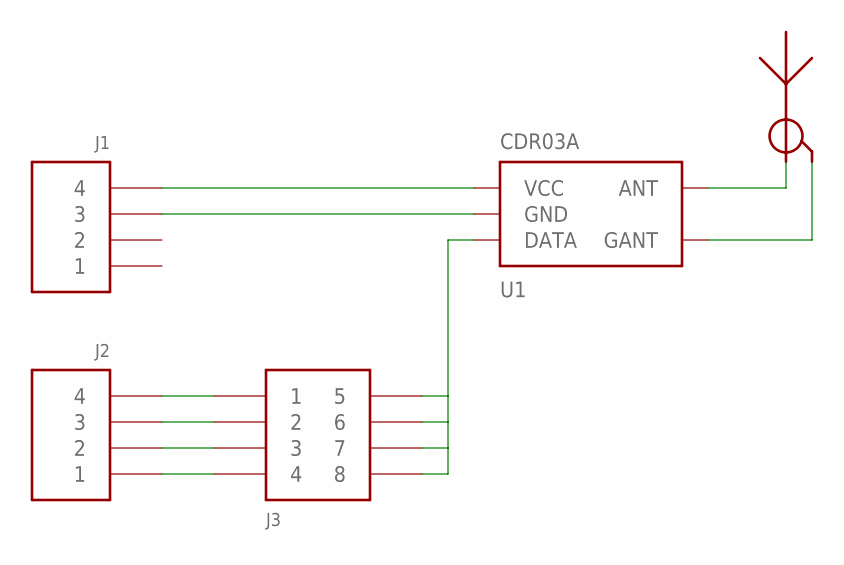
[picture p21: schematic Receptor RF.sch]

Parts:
J1, J2: 4-PIN-LINEAR-JUMPER
J3: 8-PIN-JUMPER
U1: CDR03A
U$3: ANTENNA

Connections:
unnamed: J1.P$4 (4), U1.VCC
unnamed: J1.P$3 (3), U1.GND
unnamed: J2.P$4 (4), J3.P$1 (1)
unnamed: U1.ANT, U$3.ANT
unnamed: U1.GANT, U$3.GANT
unnamed: J2.P$3 (3), J3.P$2 (2)
unnamed: J2.P$2 (2), J3.P$3 (3)
unnamed: J2.P$1 (1), J3.P$4 (4)
unnamed: J3.P$5 (5), J3.P$6 (6), J3.P$7 (7), J3.P$8 (8), U1.DATA1 (DATA), U1.DATA2 (DATA)

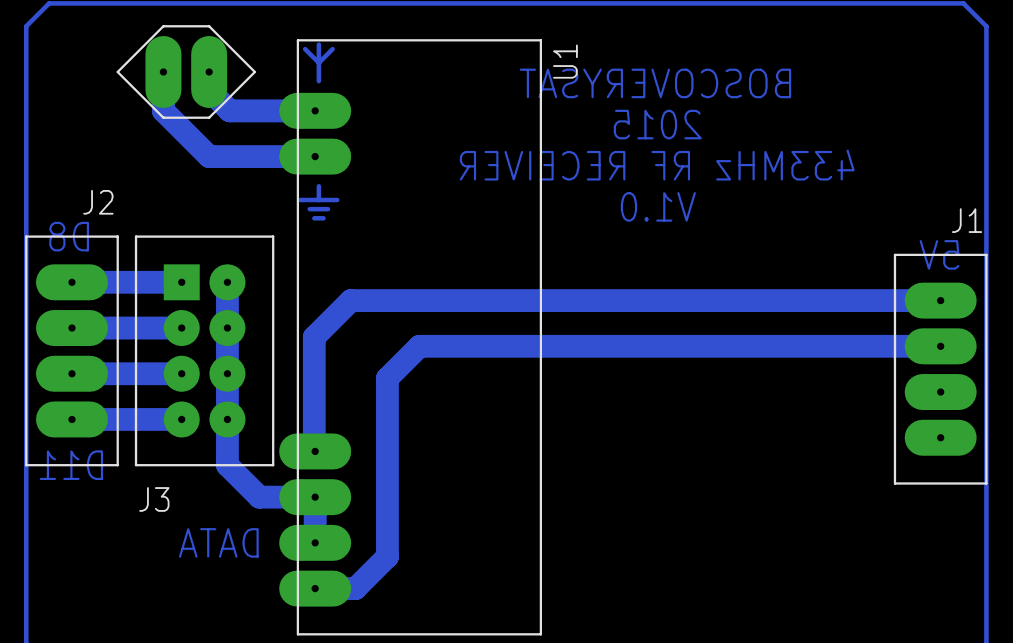
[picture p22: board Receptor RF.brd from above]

Board: 2 copper layers, 5 parts (0 on the bottom side), 9 nets.

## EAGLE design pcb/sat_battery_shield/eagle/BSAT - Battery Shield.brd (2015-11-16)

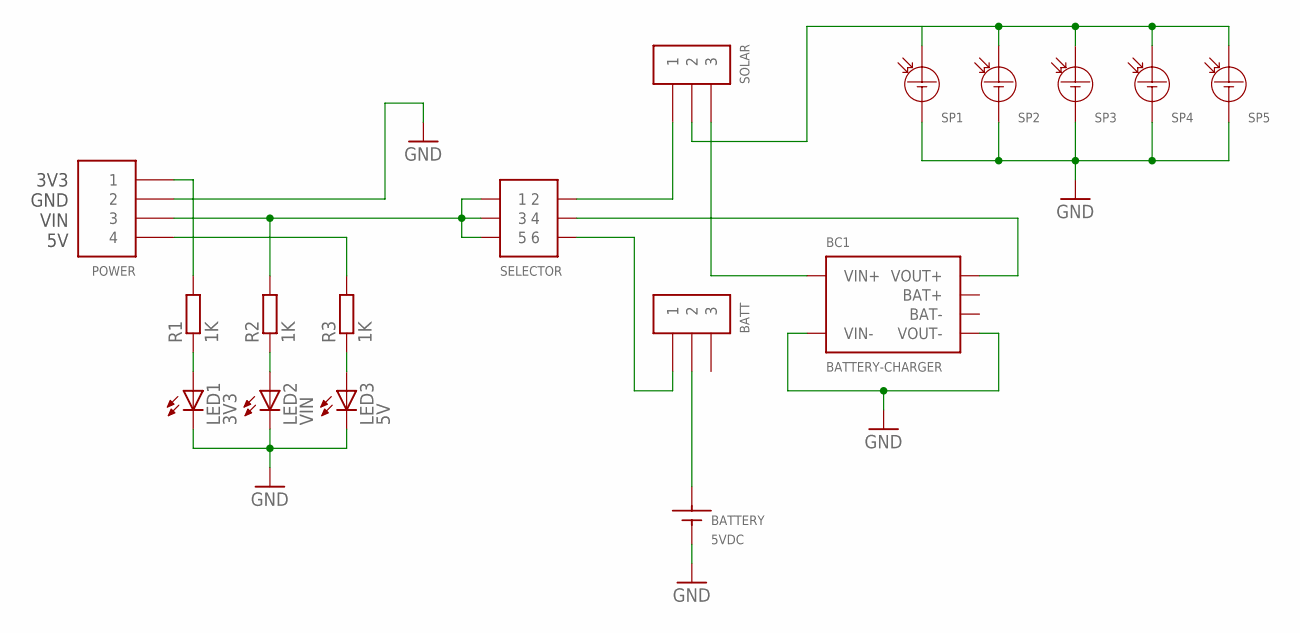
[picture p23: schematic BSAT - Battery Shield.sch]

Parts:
5VDC: BATTERY; SOLAR-PANEL
BATT: 3-PIN-JUMPER
BC1: BATTERY-CHARGER
LED1: 3V3; LED3MM
LED2: VIN; LED3MM
LED3: 5V; LED3MM
POWER: 4-PIN-DUAL-BUS; 4-PIN-LINEAL-JUMPER
R1, R2, R3: 1K; 0207/12
SELECTOR: 3-PIN-PARALEL-JUMPER
SOLAR: 3-PIN-JUMPER
SP1, SP2, SP3, SP4, SP5: SOLAR-PANEL2; SOLAR-PANEL

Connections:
GND: 5VDC.NEG, BC1.VIN-, BC1.VOUT-, LED1.K (C), LED2.K (C), LED3.K (C), POWER.2A (2), POWER.2B (2), SP1.NEG, SP2.NEG, SP3.NEG, SP4.NEG, SP5.NEG
unnamed: SELECTOR.2, SOLAR.1
unnamed: SOLAR.2, SP1.POS, SP2.POS, SP3.POS, SP4.POS, SP5.POS
unnamed: BC1.VIN+, SOLAR.3
unnamed: BC1.VOUT+, SELECTOR.4
unnamed: BATT.1, SELECTOR.6
unnamed: 5VDC.POS, BATT.2
unnamed: LED1.A, R1.1
unnamed: POWER.3A (3), POWER.3B (3), R2.2, SELECTOR.1, SELECTOR.3, SELECTOR.5
unnamed: LED2.A, R2.1
unnamed: LED3.A, R3.1
unnamed: POWER.1A (1), POWER.1B (1), R1.2
unnamed: POWER.4A (4), POWER.4B (4), R3.2

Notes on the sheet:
3V3 GND VIN 5V

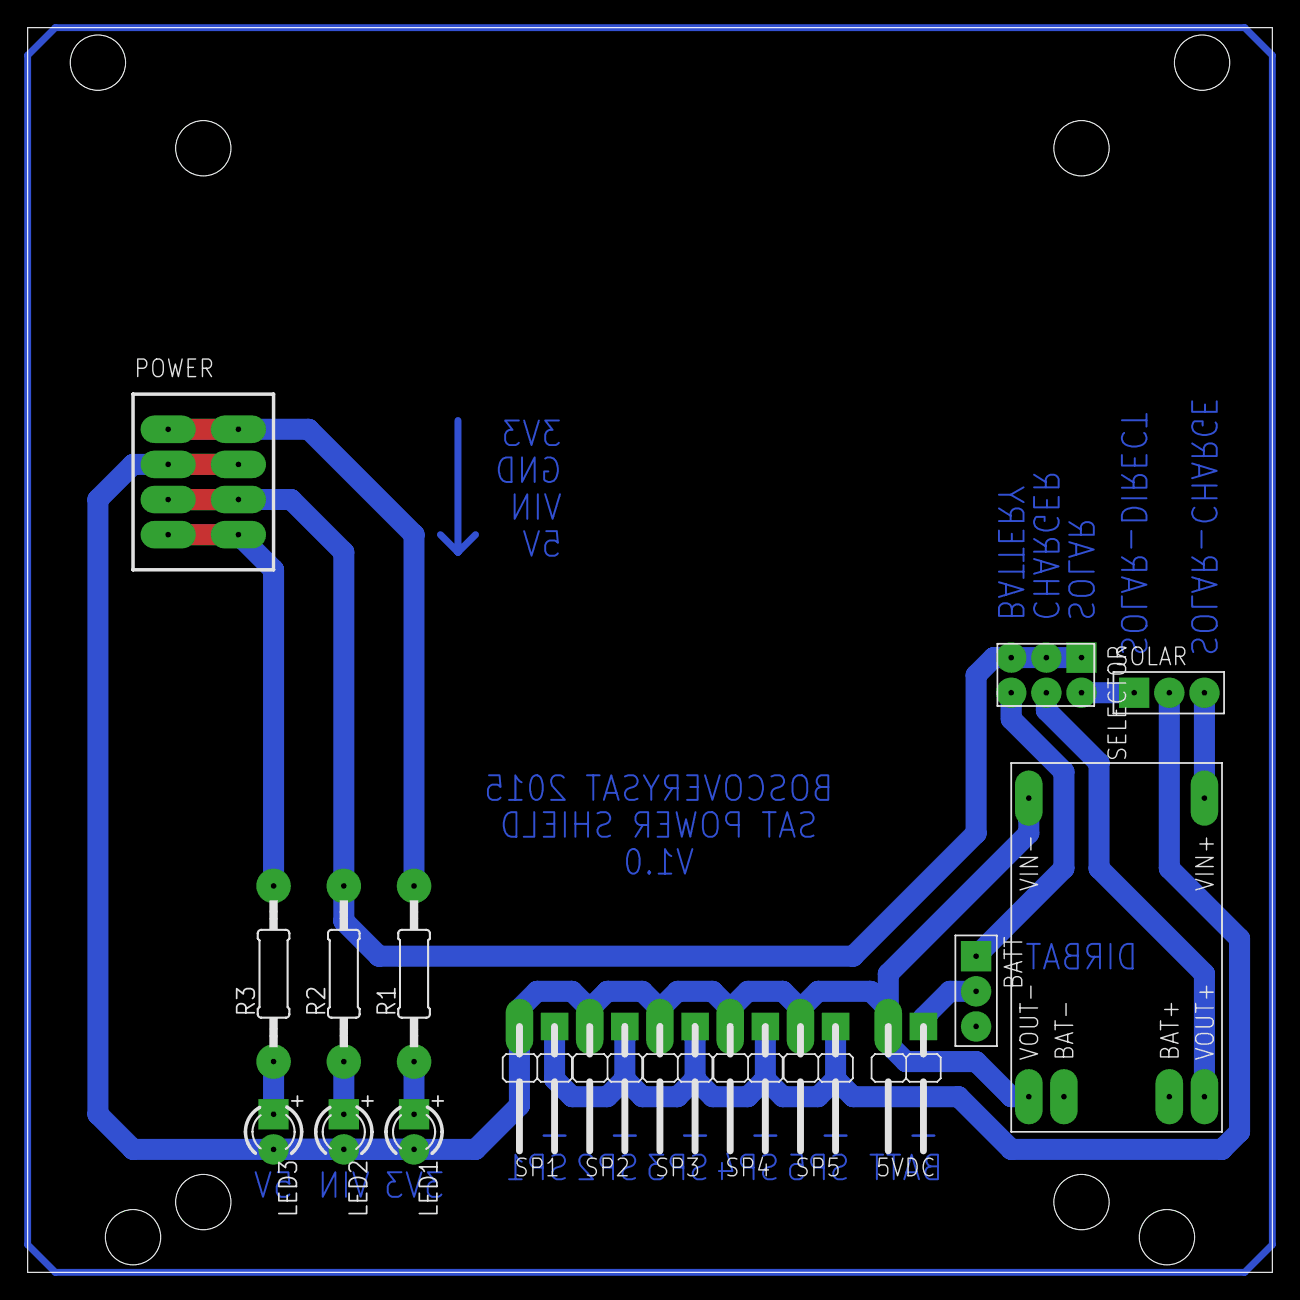
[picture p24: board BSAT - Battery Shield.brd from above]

Board: 2 copper layers, 90.0 x 90.0 mm, 17 parts (0 on the bottom side), 13 nets.

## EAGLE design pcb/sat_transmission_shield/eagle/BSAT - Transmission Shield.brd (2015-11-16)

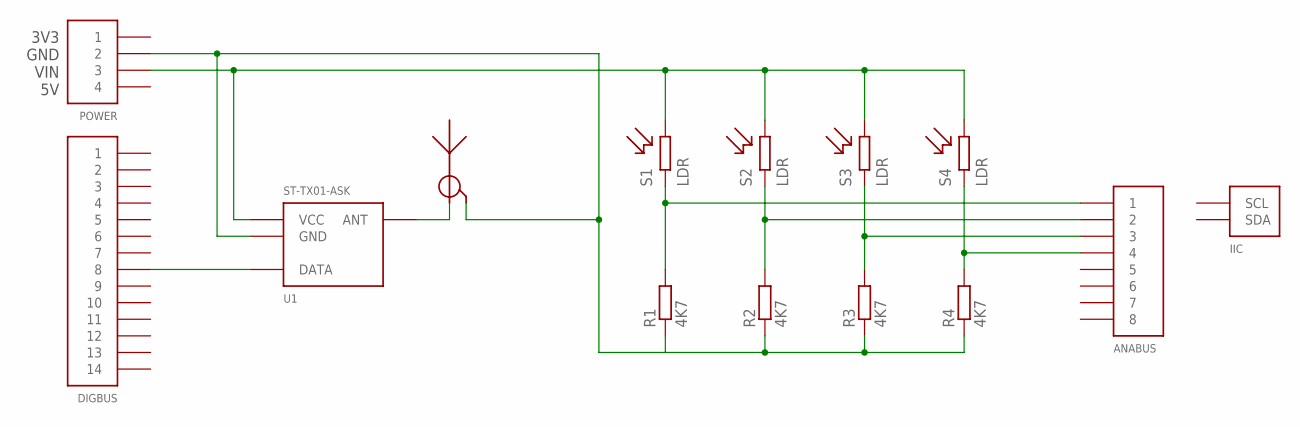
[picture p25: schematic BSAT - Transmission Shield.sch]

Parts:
ANABUS: 8-PIN-DUAL-BUS
DIGBUS: 14-PIN-DUAL-BUS
IIC: IIC-DUAL-BUS; 2-PIN-DUAL-BUS
POWER: 4-PIN-DUAL-BUS; 4-PIN-LINEAL-JUMPER
R1, R2, R3, R4: 4K7; 0207/12
S1, S2, S3, S4: LDR; 2-PIN-JUMPER
U1: ST-TX01-ASK
U$5: ANTENNA

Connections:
unnamed: ANABUS.1A (1), ANABUS.1B (1), R1.2, S1.P$2 (2)
unnamed: ANABUS.2A (2), ANABUS.2B (2), R2.2, S2.P$2 (2)
unnamed: ANABUS.3A (3), ANABUS.3B (3), R3.2, S3.P$2 (2)
unnamed: ANABUS.4A (4), ANABUS.4B (4), R4.2, S4.P$2 (2)
unnamed: POWER.3A (3), POWER.3B (3), S1.P$1 (1), S2.P$1 (1), S3.P$1 (1), S4.P$1 (1), U1.VCC
unnamed: DIGBUS.8A (8), DIGBUS.8B (8), U1.DATA
unnamed: POWER.2A (2), POWER.2B (2), R1.1, R2.1, R3.1, R4.1, U1.GND, U$5.GANT
unnamed: U1.ANT, U$5.ANT

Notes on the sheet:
3V3 GND VIN 5V

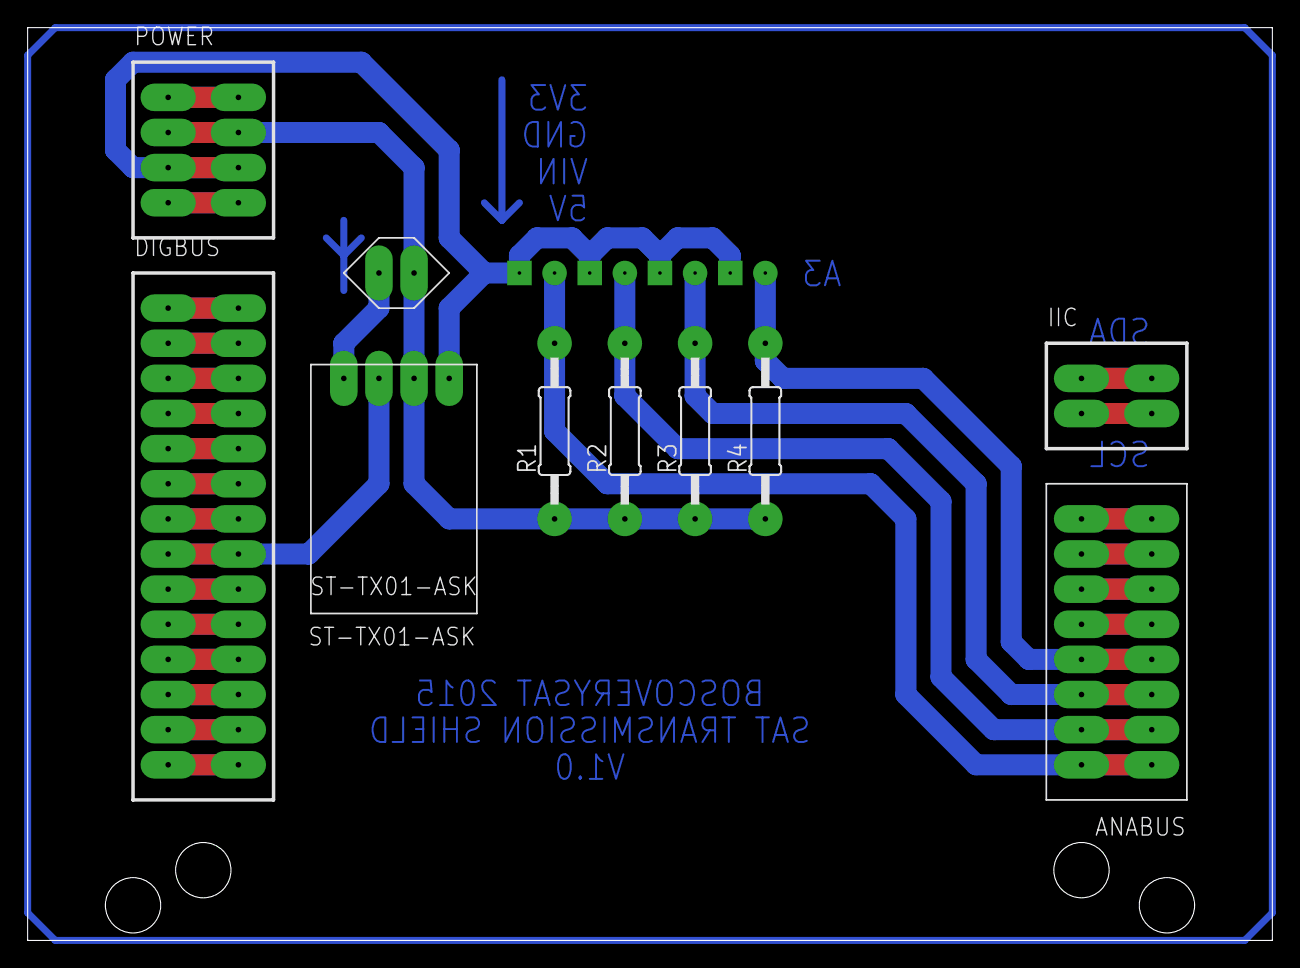
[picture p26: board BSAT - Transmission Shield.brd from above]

Board: 2 copper layers, 90.0 x 66.0 mm, 14 parts (0 on the bottom side), 8 nets.

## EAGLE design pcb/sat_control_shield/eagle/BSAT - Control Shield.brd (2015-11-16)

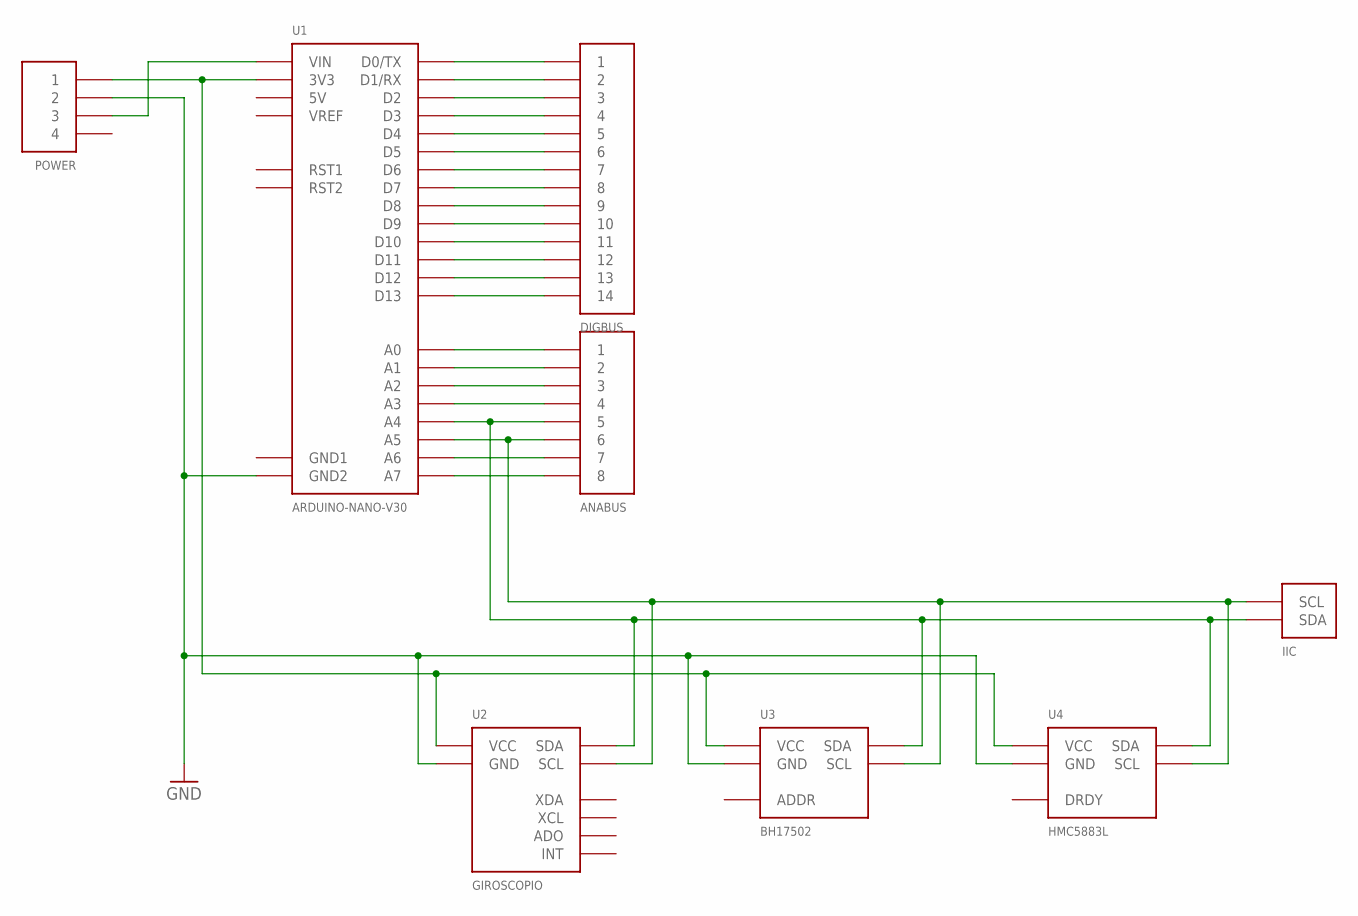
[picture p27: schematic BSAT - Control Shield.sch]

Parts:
ANABUS: 8-PIN-DUAL-BUS
DIGBUS: 14-PIN-DUAL-BUS
IIC: IIC-DUAL-BUS; 2-PIN-DUAL-BUS
POWER: 4-PIN-DUAL-BUS; 4-PIN-LINEAL-JUMPER
U1: ARDUINO-NANO-V30
U2: GIROSCOPIO
U3: BH17502; BH1750-2
U4: HMC5883L

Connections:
5V: U1.5V
GND: POWER.2A (2), POWER.2B (2), U1.GND2, U2.GND, U3.GND, U4.GND
GND1: U1.GND1
unnamed: DIGBUS.1A (1), DIGBUS.1B (1), U1.D0/TX
unnamed: DIGBUS.2A (2), DIGBUS.2B (2), U1.D1/RX
unnamed: POWER.3A (3), POWER.3B (3), U1.VIN
unnamed: POWER.1A (1), POWER.1B (1), U1.3V3, U2.VCC, U3.VCC, U4.VCC
unnamed: ANABUS.8A (8), ANABUS.8B (8), U1.A7
unnamed: ANABUS.7A (7), ANABUS.7B (7), U1.A6
unnamed: ANABUS.6A (6), ANABUS.6B (6), IIC.2A (SCL), IIC.2B (SCL), U1.A5, U2.SCL, U3.SCL, U4.SCL
unnamed: ANABUS.5A (5), ANABUS.5B (5), IIC.1A (SDA), IIC.1B (SDA), U1.A4, U2.SDA, U3.SDA, U4.SDA
unnamed: ANABUS.4A (4), ANABUS.4B (4), U1.A3
unnamed: ANABUS.3A (3), ANABUS.3B (3), U1.A2
unnamed: ANABUS.2A (2), ANABUS.2B (2), U1.A1
unnamed: ANABUS.1A (1), ANABUS.1B (1), U1.A0
unnamed: DIGBUS.3A (3), DIGBUS.3B (3), U1.D2
unnamed: DIGBUS.4A (4), DIGBUS.4B (4), U1.D3
unnamed: DIGBUS.5A (5), DIGBUS.5B (5), U1.D4
unnamed: DIGBUS.6A (6), DIGBUS.6B (6), U1.D5
unnamed: DIGBUS.7A (7), DIGBUS.7B (7), U1.D6
unnamed: DIGBUS.8A (8), DIGBUS.8B (8), U1.D7
unnamed: DIGBUS.9A (9), DIGBUS.9B (9), U1.D8
unnamed: DIGBUS.10A (10), DIGBUS.10B (10), U1.D9
unnamed: DIGBUS.11A (11), DIGBUS.11B (11), U1.D10
unnamed: DIGBUS.12A (12), DIGBUS.12B (12), U1.D11
unnamed: DIGBUS.13A (13), DIGBUS.13B (13), U1.D12
unnamed: DIGBUS.14A (14), DIGBUS.14B (14), U1.D13
VREF: U1.VREF

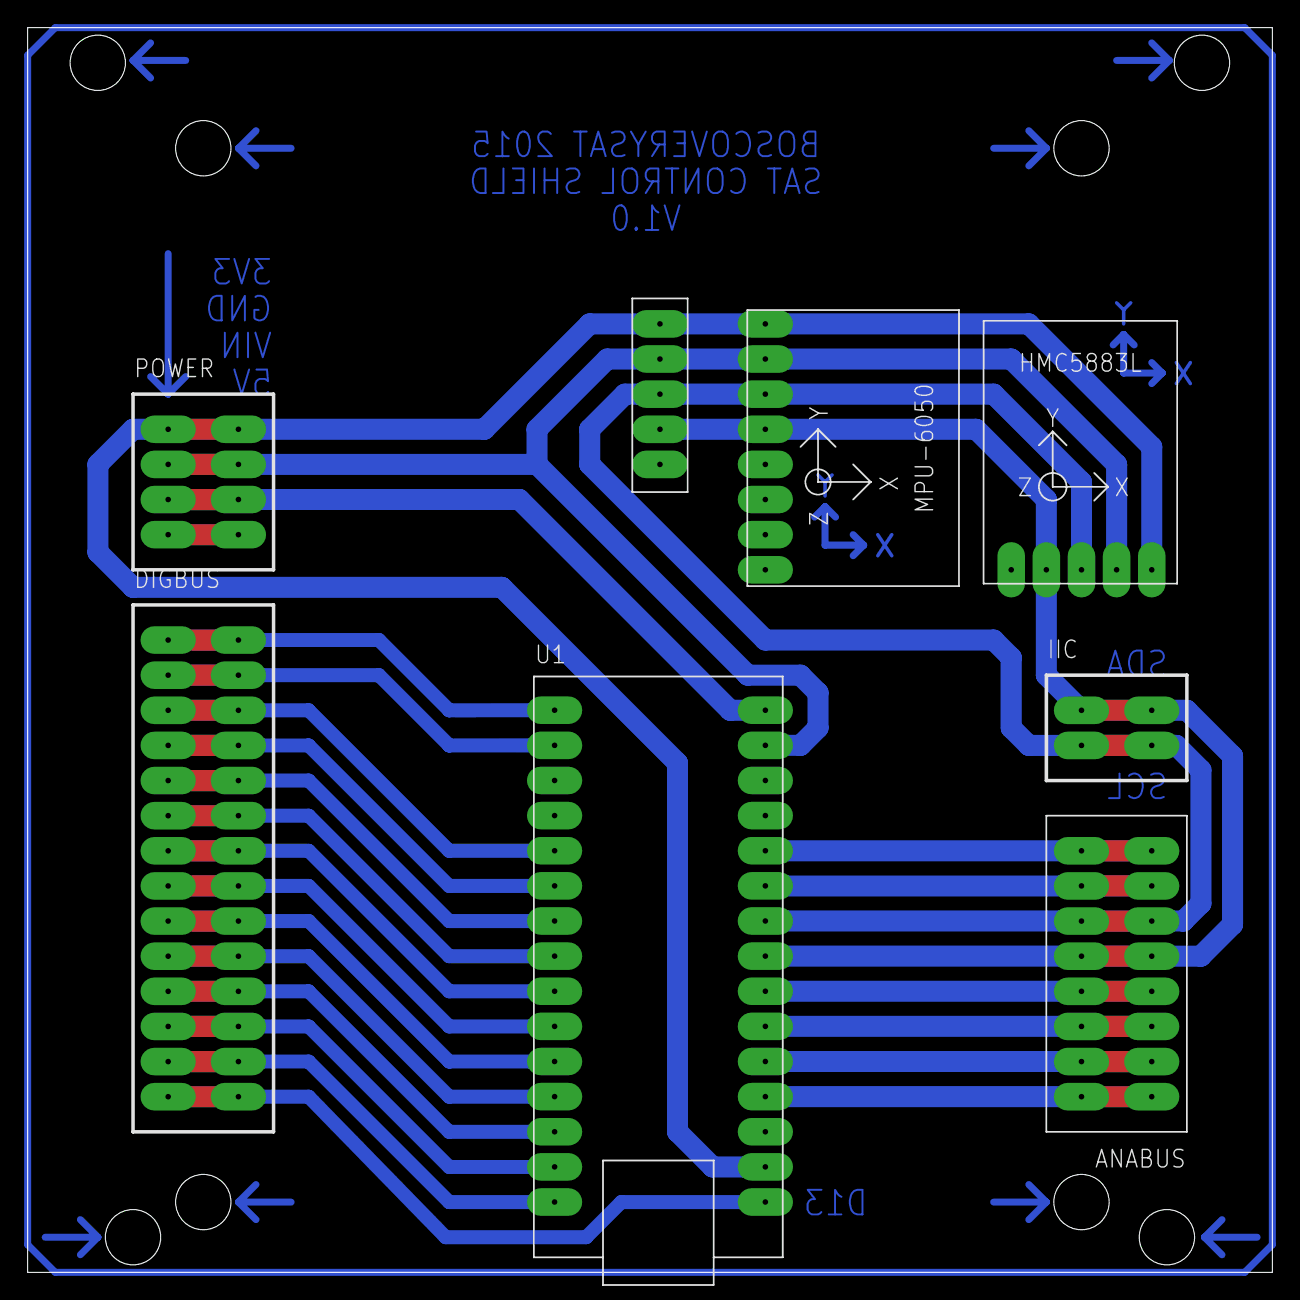
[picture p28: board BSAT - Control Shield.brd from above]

Board: 2 copper layers, 90.0 x 90.0 mm, 8 parts (0 on the bottom side), 25 nets.

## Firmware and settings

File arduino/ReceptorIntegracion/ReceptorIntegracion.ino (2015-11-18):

/****************************
  Receptor 434Test

  Este sketch comprueba el funcionamiento basico de un receptor ASK
 similar al RXB1. 

  Author: @goyoregalado

  
  Este codigo se deriva del codigo de ejemplo de la libreria radiohead.
  http://www.airspayce.com/mikem/arduino/RadioHead/
  
******************************/

#include <RH_ASK.h>
#include <SPI.h> // Not actualy used but needed to compile

RH_ASK driver;

void setup()
{
    Serial.begin(9600);
    if (!driver.init())
         Serial.println("init failed");
}

void loop()
{
    uint8_t buf[RH_ASK_MAX_MESSAGE_LEN];
    uint8_t buflen = sizeof(buf);

    if (driver.recv(buf, &buflen)) // Non-blocking
    {
	int i;
        buf[buflen] = '\0';
        String output((char *)buf);
        Serial.println(output);
    }
}

char *copyBuffer(uint8_t *buf, uint8_t buflen) {
  char buffer[buflen + 1];
  
  for (int i = 0; i < buflen; i++) {
    buffer[i] = (char) buf[i];
  }
  buffer[buflen] = '\0';
  return buffer;
}

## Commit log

2015-11-07 Prototipo en desarrollo del software de Telemetría
2015-11-13 Con datos de prueba
2015-11-16 [ FEATURE ] - Añadidos esquemas y PCBs de satélite y receptor de RF.
    [BSAT - Battery Shield.brd, BSAT - Battery Shield.sch, BSAT - Control Shield.brd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]
2015-11-16 [ UPDATE ] - Actualizada imagen del PCB para el receptor de RF.
2015-11-16 Actualizado el Software
2015-11-17 Añadidos logos y zona para la representación 3D
2015-11-18 Software Estación de Tierra
2015-11-18 Añadida la carpeta Arduino
2015-11-20 [ UPDATE ] - Añadiendo procesamiento de telemetría mediante NodeJS.
2015-11-20 [ REPO UPDATE ] - Carpeta de módulos de NodeJS eliminada.
2016-05-25 feat(battery-shield): Diseños basados en KiCAD añadidos.
    [BSAT - Battery Shield.kicad_pcb, BSAT - Battery Shield.sch]
2016-05-26 chore(gitignore): File updated in order to avoid track .DS_Store files.
2016-05-26 chore(boscoverysat-lib): Arduino Nano V3.0 and 443 transmisor schema symbols attached.
2016-05-26 feat(control-shield): KiCAD project created for this shield.
    [BSAT - Control Shield.kicad_pcb, BSAT - Control Shield.sch]
2016-05-27 feat(control-shield): Working on.
    [BSAT - Control Shield.kicad_pcb, BSAT - Control Shield.sch]
2016-05-29 feat(boscoverysat-lib): Arduino Nano v3, sensor luminos BH1750 y emisor de radio CDT-88 añadidos a la librería.
2016-05-29 refactor(battery-shield): Esquema actualizado.
    [BSAT - Battery Shield.sch]
2016-05-29 refactor(control-shield): Esquema y PCB rediseñadas a la versión v1.1 mediante KiCAD.
2016-05-30 feat(boscoverysat-lib): Sensor de temperatura HTU21D añadido.
2016-05-30 feat(control-shield): Sensor de temperatura HTU21D añadido.
    [BSAT - Control Shield.kicad_pcb, BSAT - Control Shield.sch]
